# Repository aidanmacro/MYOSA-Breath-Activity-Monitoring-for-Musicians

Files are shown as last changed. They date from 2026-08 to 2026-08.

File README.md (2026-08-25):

## BreathSense - MYOSA Musical Breath Activity

<p align="center">
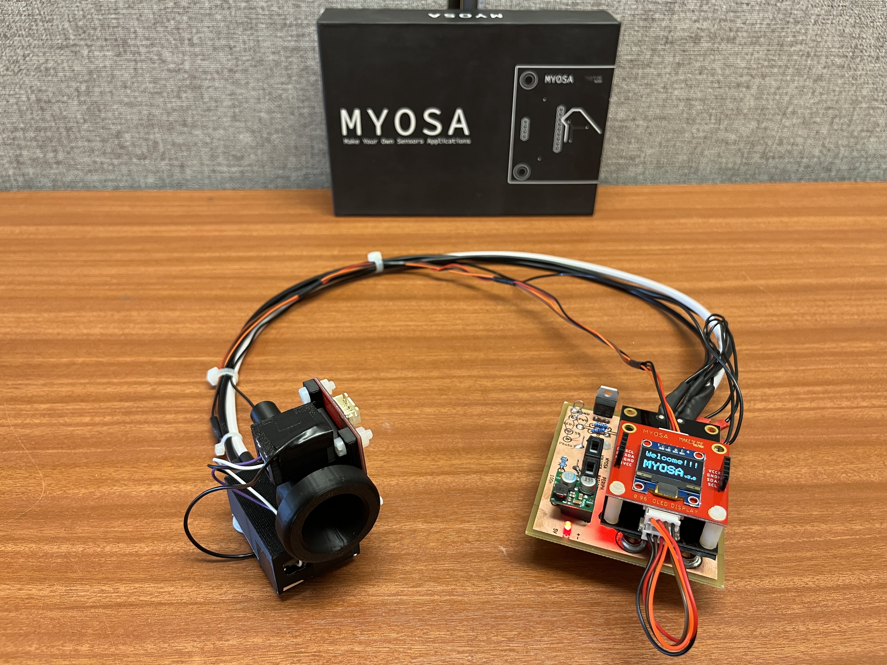
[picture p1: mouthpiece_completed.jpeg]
  <br/>
  <i>Breathsense: a CO2 Detecting mouthpiece using MYOSA board and sensors.</i>
</p>

## Acknowledgements

- Dr. Vincenzo Pusino
- Ben Allen
- University of Glasgow
- University of Glasgow Technical Staff

## Overview

Musicians rely heavily on breath control to shape dynamics, phrasing, tone and endurance, yet there are few accessible ways to measure breathing behaviour objectively during real performance. This project develops a real-time breath monitoring system designed specifically for musicians, using exhaled CO₂, pressure and temperature data to provide direct insight into how breath is being used while playing. The system is built around the MYOSA development board, providing an IoT-capable platform for sensor integration, wireless communication and real-time data logging. A custom Non-Dispersive Infrared (NDIR) CO₂ sensing system detects exhaled breath, while pressure and temperature measurements provide complementary information about breath activity and environmental variation. By combining these sensing methods with wireless data transmission and live visualisation, the project aims to provide musicians, teachers and researchers with a practical tool for analysing breath strength, timing and consistency during practice and performance.

#### Key Features

  - Custom NDIR CO₂ Sensor to allow most direct measurement. 
  - Pressure sensor for additional cross validation data and enhanced insights. 
  - Built on the MYOSA MCU platform, small enough to clip to a belt or pocket, streaming data live
  - On device OLED display for seeing quick analytics 
  - Python based WiFi/IoT system enabling cloud computing for in depth real time signal processing.

## Demo / Examples

### Images

<p align="center">
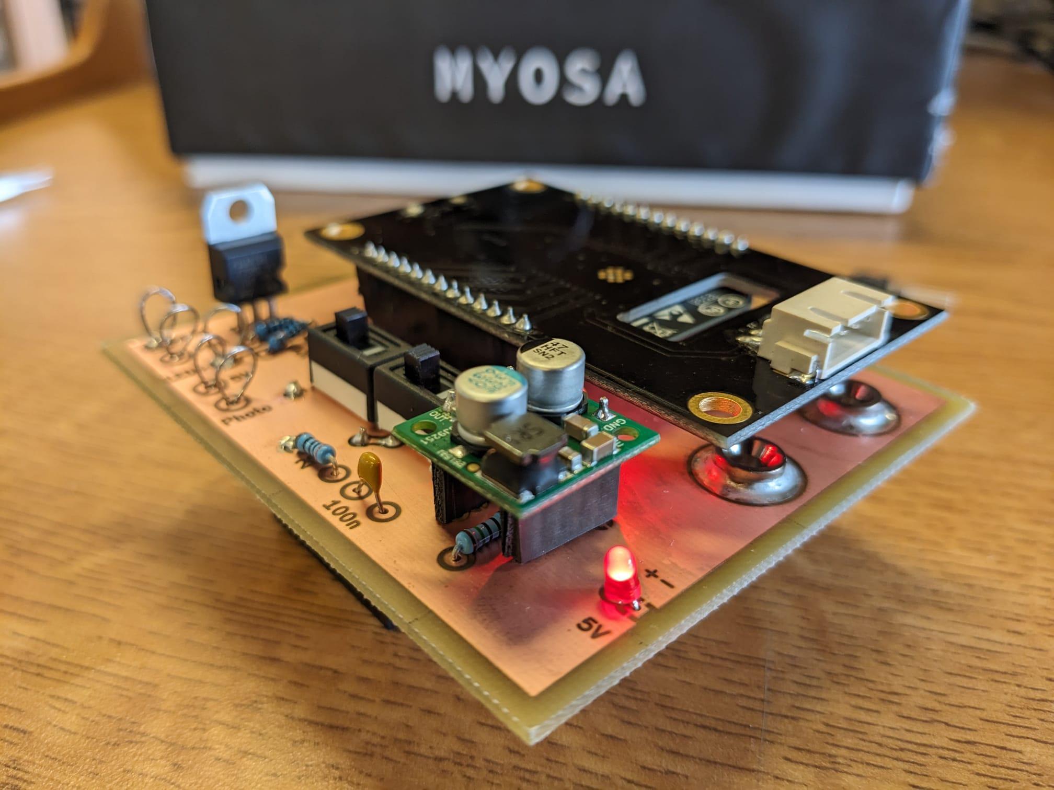
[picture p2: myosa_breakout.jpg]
  <br/>
  <i>Closeup of MYOSA breakout board.</i>
</p>

<p align="center">
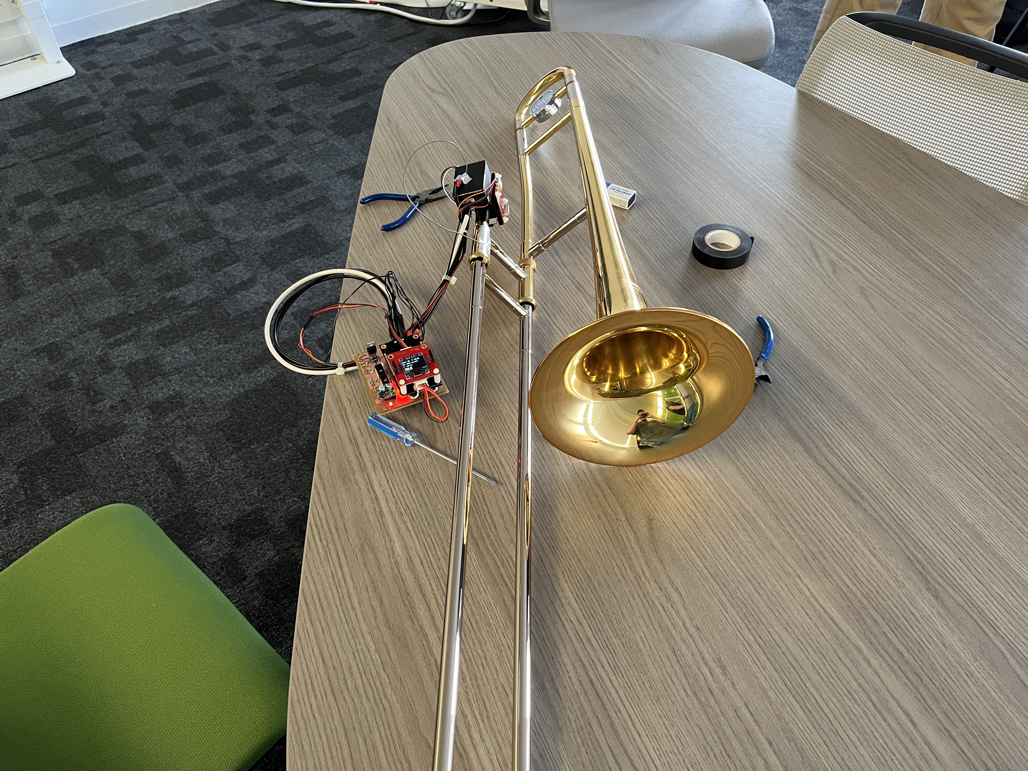
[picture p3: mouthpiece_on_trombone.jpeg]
  <br/>
  <i>Mouthpiece attached to real instrument.</i>
</p>

### Videos

<video controls width="100%">
  <source src="./breathsense_promovid.mp4" type="video/mp4">
</video>

## Features (Detailed)

## 1. NDIR CO₂ Sensing

The primary breath measurement is provided by a custom Non-Dispersive Infrared (NDIR) sensing system. CO₂ absorbs infrared radiation at specific wavelengths, so the concentration of CO₂ in exhaled breath can be inferred from the reduction in transmitted infrared light.

A mid-wave infrared (MWIR) LED is used as the optical source. The LED is pulsed rather than operated continuously, reducing average power consumption while also allowing the system to distinguish the desired optical signal from ambient infrared radiation and other sources of interference.

The emitted infrared light passes through the mouthpiece and the musician's exhaled breath before reaching a photodiode. As the concentration of CO₂ in the airflow changes, the amount of infrared radiation reaching the photodiode changes accordingly. The photodiode output is converted into a measurable voltage using an analogue front end before being sampled by the MYOSA board.

The system uses synchronous detection to improve the measurement. The photodiode is sampled in synchronisation with the LED pulses, allowing the signal measured when the LED is active to be compared with the background signal when it is inactive. This helps reject ambient infrared light and other sources of background variation.

The resulting CO₂ signal is used as a proxy for breath activity. Rather than attempting to measure the musician's breathing volume directly, the system provides a real-time indication of changes in exhaled CO₂ as the musician plays.

## 2. Pressure and Temperature Sensing

The optical CO₂ measurement is complemented by pressure and temperature measurements from a BMP180 sensor connected to the MYOSA board over I²C.

Pressure provides an independent measurement of activity within the mouthpiece. Changes in mouthpiece pressure can therefore be compared with the CO₂ signal to help distinguish genuine breath activity from changes or noise in the optical measurement.

Temperature is also recorded because the operating environment of the sensor can change during use. Monitoring temperature provides additional information for accounting for environmental variation and thermal drift in the measurements.

Combining the three measurements gives a more informative representation of breath activity than relying on the CO₂ channel alone.

## 3. Real-Time Breath Monitoring

The sensor data is processed into a real-time representation of the musician's breath activity. Changes in the measured CO₂ concentration can be visualised as a capnogram, allowing the user to observe the timing and relative strength of their breath while playing.

The pressure signal provides an additional reference alongside the CO₂ measurement, while temperature data can be used to identify environmental changes and compensate for drift.

This allows breath activity to be observed during actual playing rather than requiring the musician to perform a separate breathing test.

## 4. MYOSA Integration and Wireless Data

The sensing hardware is integrated with the MYOSA development board, which acts as the central controller for the system. The board controls the pulsed LED, reads the analogue CO₂ sensing circuitry, and communicates with the BMP180 over I²C.

The measurements are combined into a timestamped data stream and transmitted wirelessly to an external computer. This separates the sensing hardware from the visualisation system, allowing the musician to carry the relatively small sensing unit while viewing the measurements on a separate device.

Wireless transmission also allows measurements to be logged for later analysis rather than limiting the system to live monitoring.

## 5. Real-Time Visualisation

A Python and PyQt desktop application receives the wireless sensor data and displays the CO₂, pressure and temperature channels in real time.

The application performs additional signal processing and filtering before displaying the measurements, allowing the user to see changes in breath activity as they occur.

Session data can also be buffered for later review, making it possible to compare different playing sessions and examine breath behaviour beyond the immediate live display.

## 6. Potential Musical Application

By capturing quantifiable breath data during real playing, this system opens up several practical applications:

- **Practice feedback** musicians can see how their breath support and timing align with phrasing, dynamics, and endurance across a piece, rather than relying on subjective feel alone.
- **Teaching aid** instructors can use recorded breath data to give concrete, visual feedback on breath control technique, rather than description alone.
- **Endurance and consistency tracking** repeated sessions can be compared over time to track improvements in breath efficiency or stamina for demanding passages.
- **Research** objective breath-activity data across players/instruments could support studies into breath technique and fatigue in wind and brass performance.

## Usage Instructions

The final version of the device is envisioned to work like so:

- Attach mouthpiece to wind instrument and place MYOSA in pocket/hook to belt
- Run accompanying app on phone/computing device
- Allow hardware a few seconds unplayed to calibrate CO2 background level
- Practise instrument as normal, playing along to sheet music on app
- Compare breath activity in app in realtime and/or observe collected data at end of piece

## Tech Stack

### Hardware

| Component | Part | Role |
|---|---|---|
| MCU / wireless | MYOSA development board | Master controller — drives sensing, fuses data, streams wirelessly to host computer/Cloud |
| CO₂ emitter | L15895-0430MA LED | Pulsed mid-wavelength infrared (MWIR) source, tuned to a CO₂ absorption band |
| CO₂ detector | P16112-011MA photodiode | Measures transmitted IR intensity after passing through the breath sample |
| Pressure / temperature | BMP180 (Minkit breakout) | I²C sensor providing an independent breath-pressure signal and temperature compensation |
| Onboard display | 0.96" OLED Display (Minkit breakout) | I²C enabled, providing on device quick insights for potential offline use|
| Mechanical | 3D-printed trombone mouthpiece | Directs exhaled breath through the sensing chamber; mounts sensor package in the airflow path (Based on Popular Bach 12C Design) |
| PCB | Custom board (see `KiCAD/`) | Houses the analog front end and sensor interconnects |

#### Analog Front End

The CO₂ channel is the most sensitive part of the hardware, since NDIR absorption signals are small relative to the raw photodiode output. The front end is built around a **pulsed detection scheme**:

1. **LED pulsing** — the MWIR LED is driven in short pulses (rather than continuously) by the MYOSA board. Pulsing reduces average power draw and, more importantly, lets the readout distinguish the LED's signal from ambient IR and photodiode drift.
2. **Photodiode readout** — the photodiode's current output is converted to a voltage via a transimpedance amplifier (TIA), since photodiode signals are typically too small and too high-impedance to read directly with an ADC.
3. **Filtering** — the amplified signal is filtered to reject noise outside the LED's pulse frequency and suppress ambient light interference.
4. **Synchronous sampling** — the MYOSA board samples the photodiode signal in sync with the LED pulse (on-pulse vs off-pulse), allowing the background/ambient signal to be subtracted from the CO₂-modulated signal. This differential approach is what makes the CO₂ absorption measurable despite a noisy optical environment.
5. **Digitisation** — the conditioned analog signal is read via the MYOSA board's ADC and combined in firmware with the BMP180's I²C readings.

### Software

**Firmware — Arduino C++ (runs on MYOSA)**
- Drives LED pulse timing and synchronises photodiode ADC sampling with each pulse
- Polls the BMP180 over I²C for pressure and temperature
- Fuses CO₂, pressure, and temperature readings into a single timestamped data frame
- Streams the fused data frame wirelessly to the host computer

**Desktop application — Python + PyQt**
- Listens for the incoming data stream from the MYOSA board and parses each frame into CO₂, pressure, and temperature values
- Does enhanced signal processing and filtering
- Plots all three channels live using PyQt's graphing widgets, updating in real time as the musician plays
- Buffers session data for post-session review, and (per the Usage Instructions) supports comparing breath activity against sheet music playback

## Requirements / Installation

**Dependencies** are listed in `requirements.txt` — install with:
```bash
pip install -r requirements.txt
```
**User Interface** run the current user interface using:
```bash
python3 .\Code\app_code\Breathsense_GUI.py
```

## Repository Structure

| Folder | Contents |
|---|---|
| [`Code/`](Code) | Arduino C++ firmware for the MYOSA board (sensor reading, LED pulsing, I²C fusion, wireless streaming) and the Python/PyQt desktop visualisation app |
| [`KiCAD/`](KiCAD) | PCB schematics and layout for the custom analog front end (NDIR CO₂ sensing circuitry) |
| [`Mechanical/`](Mechanical) | 3D-printable mouthpiece adapter design (based on a Bach 12C mouthpiece) that houses the sensor package in the airflow path |

## License MIT License

Copyright (c) 2026 aidanmacro

Permission is hereby granted, free of charge, to any person obtaining a copy of this software and associated documentation files (the "Software"), to deal in the Software without restriction, including without limitation the rights to use, copy, modify, merge, publish, distribute, sublicense, and/or sell copies of the Software, and to permit persons to whom the Software is furnished to do so, subject to the following conditions:

The above copyright notice and this permission notice shall be included in all
copies or substantial portions of the Software.

THE SOFTWARE IS PROVIDED "AS IS", WITHOUT WARRANTY OF ANY KIND, EXPRESS OR IMPLIED, INCLUDING BUT NOT LIMITED TO THE WARRANTIES OF MERCHANTABILITY, FITNESS FOR A PARTICULAR PURPOSE AND NONINFRINGEMENT. IN NO EVENT SHALL THE AUTHORS OR COPYRIGHT HOLDERS BE LIABLE FOR ANY CLAIM, DAMAGES OR OTHER LIABILITY, WHETHER IN AN ACTION OF CONTRACT, TORT OR OTHERWISE, ARISING FROM, OUT OF OR IN CONNECTION WITH THE SOFTWARE OR THE USE OR OTHER DEALINGS IN THE
SOFTWARE.

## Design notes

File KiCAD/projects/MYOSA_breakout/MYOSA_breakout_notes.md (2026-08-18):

**NOTES**

&#x09;**PinHeader\_1x13\_P2.54mm\_Vertical.step**

&#x09;

&#x09;Uni has KiCAD v9.01.

&#x09;

&#x09;CANT USE ADC2 WITH WIFI! Using 'sensor\_vp' as this is definitely ADC1\_CH0.	It doesn't have internal pulldown though so that's been added.	

&#x09;Pretty sure the onboard regulator will safely power the esp32 from VIN with	4.5-12V.

&#x09;Need high current for LED and 3V3 available for opamp circuit.

&#x09;Just use onboard 3V3 and external 5V? How about 4xAA at 6V?

&#x09;could 3v3 output on MYOSA power opamps? Yes, it doesn't really draw power.

&#x09;Want to make easy access for powering with PSU. Switch to choose between 	battery and PSU? If MYOSA is plugged in, still need 5V for LED.

&#x09;	battery: powering both MYOSA and LED

&#x09;	PSU: powering both MYOSA and LED

&#x09;	USB: Powers only MYOSA, battery/PSU required for LED

&#x09;Test points? 

&#x09;	

&#x09;	Voltage sources

&#x09;	PWM out

&#x09;	Either end of LED

**Measurements required/things to check**

&#x09;9V Battery holder

&#x09;LED Size

&#x09;Banana plugs

&#x09;Switches

&#x09;Connectors to BMP module/LED+Photodiode

&#x09;Should BMP180 be separate connector?

&#x09;Should battery be on other side?

**LED:** 1% duty cycle, 20us on, 1980us off (500Hz)

&#x09;3R4 series resistor drops 1.7V so LED has 3.3V across it, corresponding to 	\~450mA.

&#x09;P\_LED = 0.45 \* 3.3 \* 0.01 = 14.85mW

&#x09;P\_R\_SERIES = 0.45 \* 1.7 \* 0.01 = 7.65mW

**MOSFET**

&#x09;Switching freq = 500Hz

&#x09;Static drain-source on-resistance \~ 0.025R

&#x09;negligible power I think...

**MYOSA**

&#x09;Powered by 5V USB or 3.3Vin.

&#x09;Probably want to maintain 5V supply to LED so that there is a current 	limiting resistor and some headroom? Otherwise, could power with 3.3V and 	no resistor. Still need something that can supply the current spikes, MYOSA 	can't.

&#x09;ESP32 Max transmission power: 239mA (average) \* 3.3 = 789mW (Peak 379mA)

&#x09;lowest = 165mA \* 3.3 = 545mW.

has **AMS1117 (T33 F80LC)** fixed 3V3 voltage regulator.

&#x09;< 1A output

&#x09;< Absolute max 15V input (4.5-7V recommended)

&#x09;1.3V dropout at worst so 4.6V minimum

**ESP32-WROOM-32E**

&#x09;Absolute max input 3.6V. Provided 3V3 by AMS1117.

&#x09;All GPIO pins support either LED or motor PWM.

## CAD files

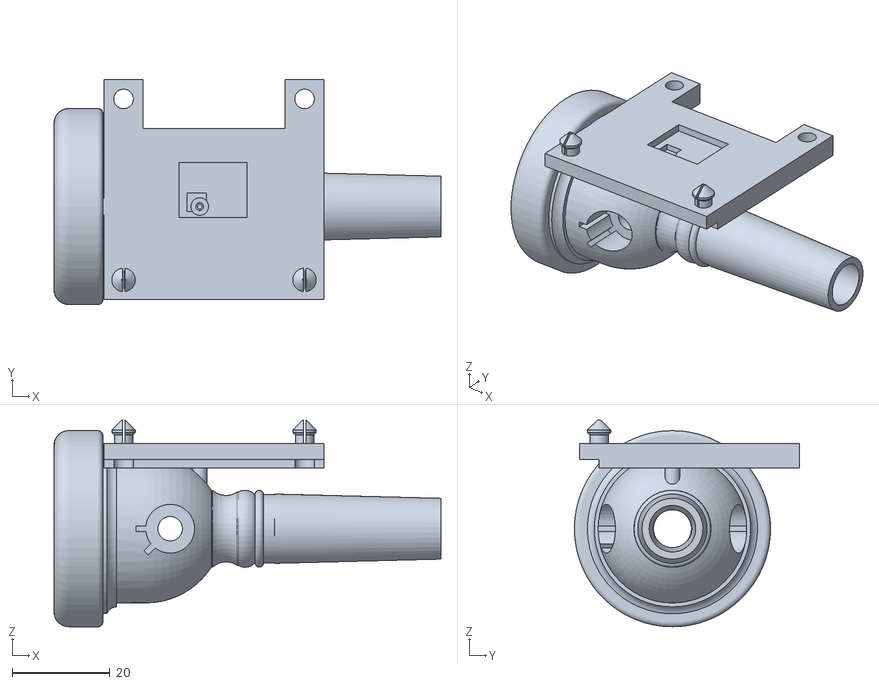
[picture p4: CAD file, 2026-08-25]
Mechanical/Mouthpiece/STLs/Full_Assem - Mouthpiece_SLD-1.STL
79.1 x 46.1 x 42.2

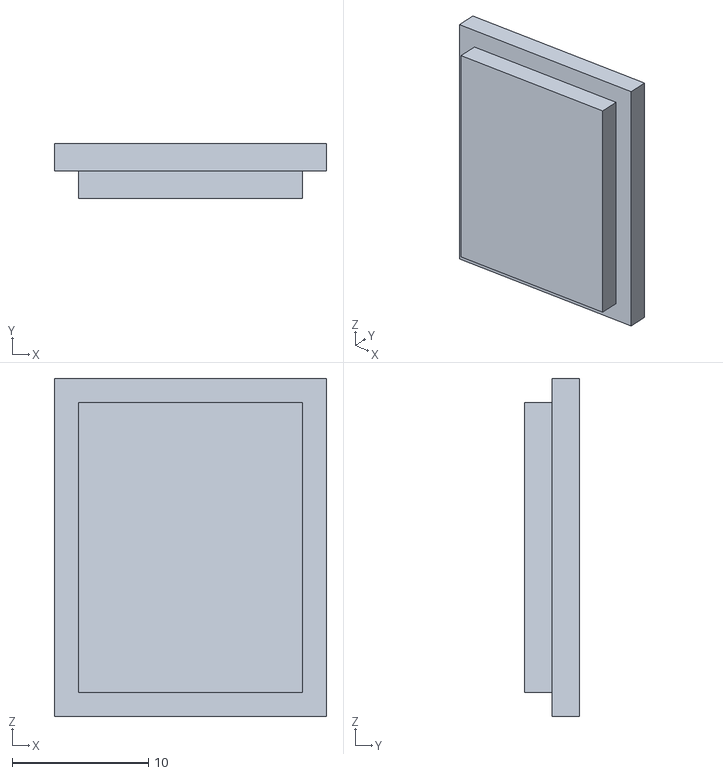
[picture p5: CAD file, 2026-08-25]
Mechanical/Mouthpiece/STLs/Full_Assem - LED_Holder_Lid-1.STL
20.0 x 4.00 x 24.8

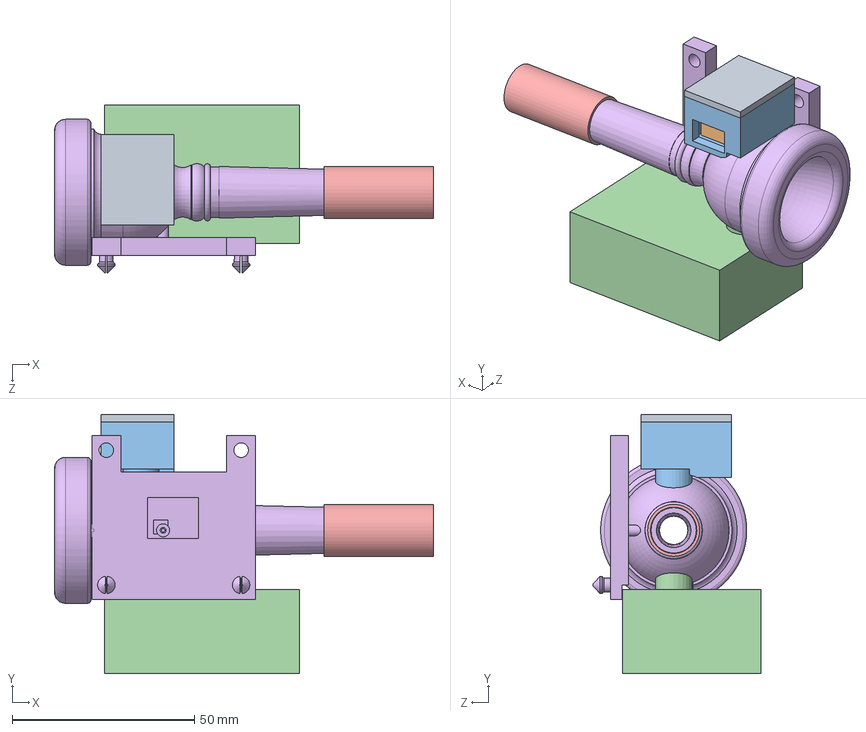
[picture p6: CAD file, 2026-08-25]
Mechanical/Mouthpiece/Full_Assem.SLDASM
104.0 x 71.1 x 46.2 mm
Mouthpiece_SLD
TrombonePort
Photodiode_Holder
LED_Holder
LED_PCB
LED_Holder_Lid

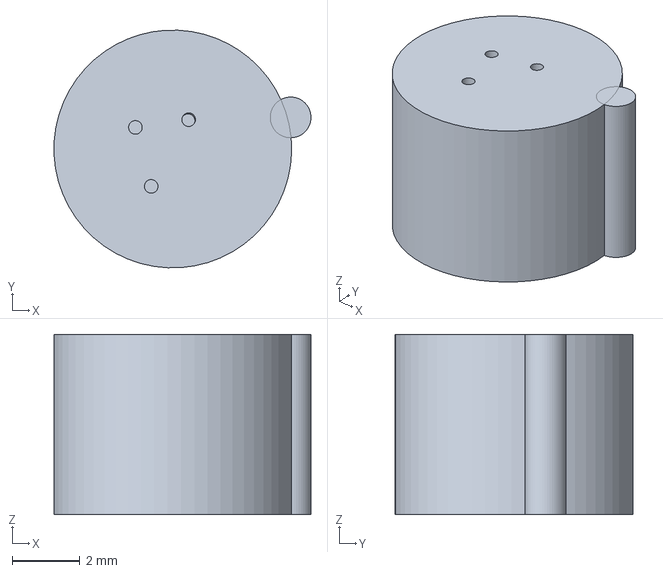
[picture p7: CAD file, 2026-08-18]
KiCAD/DST5_custom_library/3dmodels/TO46 Sheath.step
7.57 x 6.99 x 5.30 mm

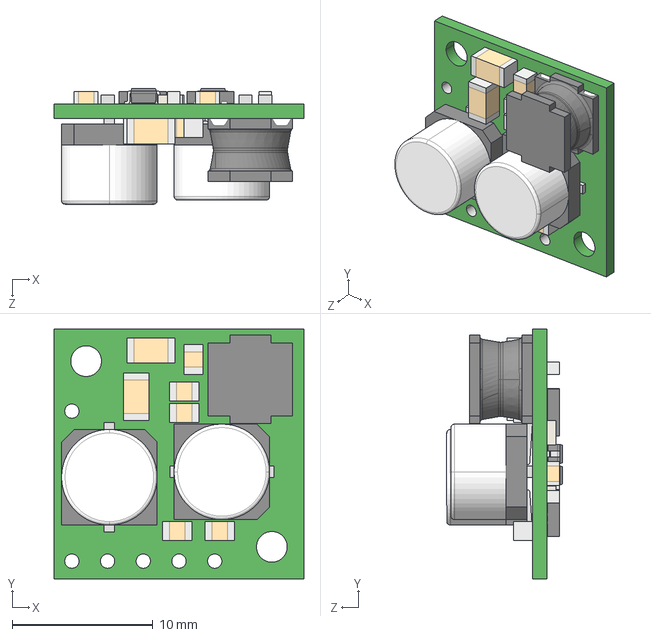
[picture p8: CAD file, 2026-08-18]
KiCAD/external_libs/pololu/d24v22fx-step-down-voltage-regulator.step
17.8 x 17.8 x 8.22 mm

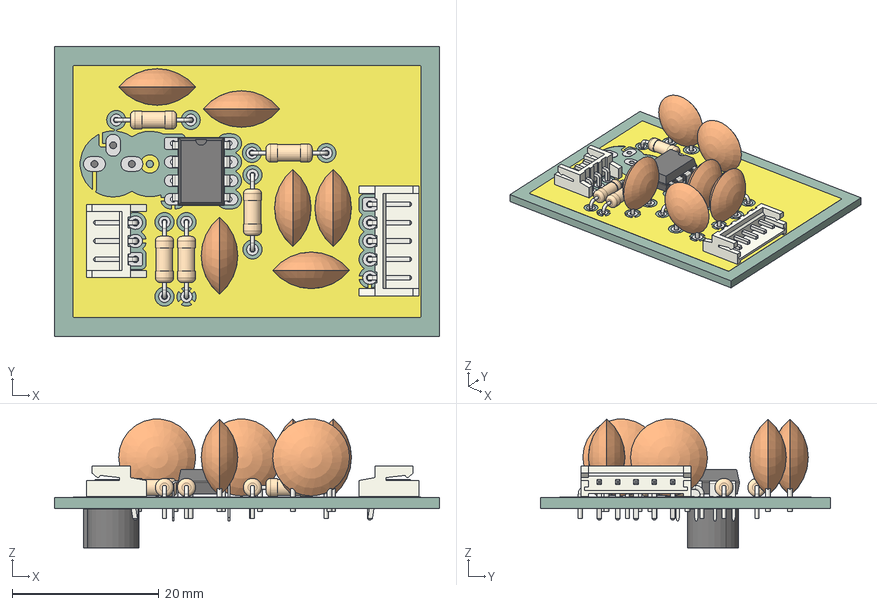
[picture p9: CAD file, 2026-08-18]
KiCAD/projects/photodiode TIA circuit/photodiode_tia_circuit/.step
52.5 x 39.5 x 17.5 mm
DIP-8_W7.62mm
JST_EH_S5B-EH_1x05_P2.50mm_Horizontal
C_Disc_D10.5mm_W5.0mm_P5.00mm x 6
R_Axial_DIN0207_L6.3mm_D2.5mm_P10.16mm_Horizontal x 5
JST_EH_S3B-EH_1x03_P2.50mm_Horizontal
TO46 Sheath
photodiode_tia_circuit_copper
photodiode_tia_circuit_pad
photodiode_tia_circuit_via
photodiode_tia_circuit_PCB

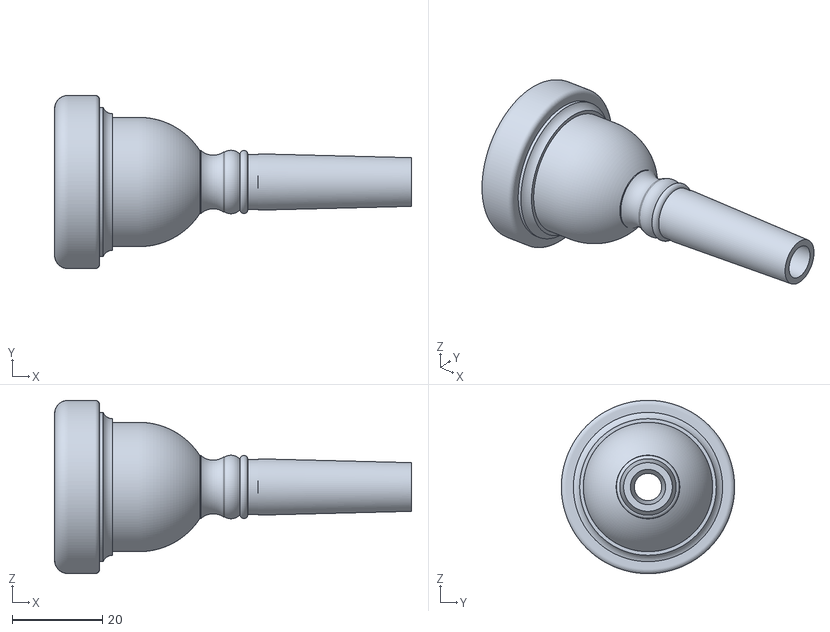
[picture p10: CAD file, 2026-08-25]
Mechanical/Mouthpiece/12C_Mouthpiece.stl
79.1 x 38.4 x 38.4

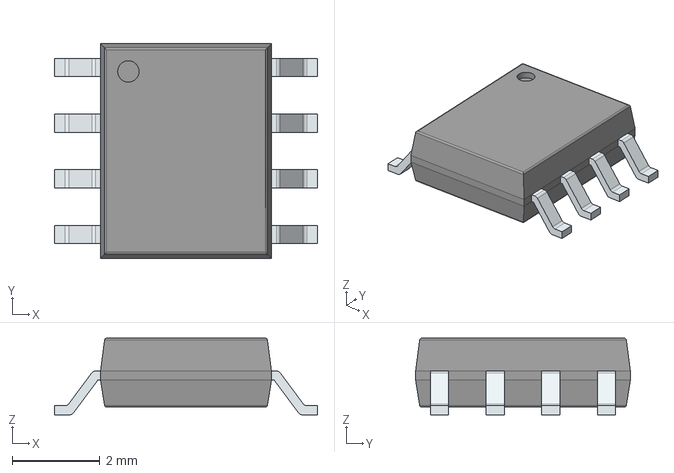
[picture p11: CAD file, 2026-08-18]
KiCAD/DST5_custom_library/3dmodels/STCS05DR.stp
6.00 x 4.90 x 1.75 mm
PinsArrayLR

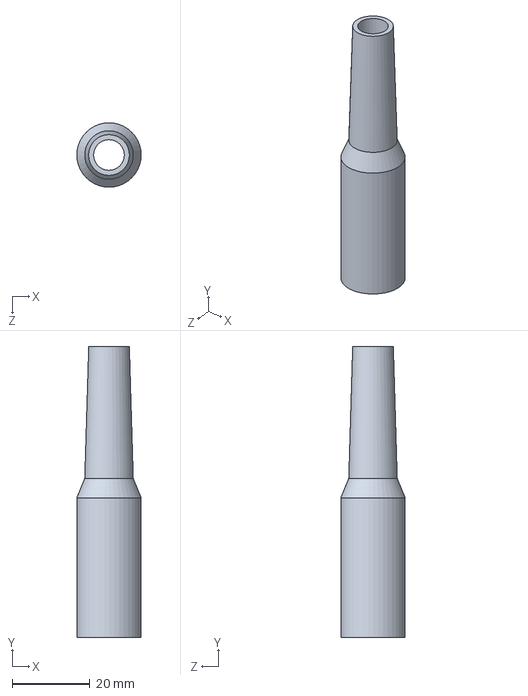
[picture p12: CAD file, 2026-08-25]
Mechanical/Mouthpiece/Adapter.SLDPRT
16.6 x 75.0 x 16.6 mm

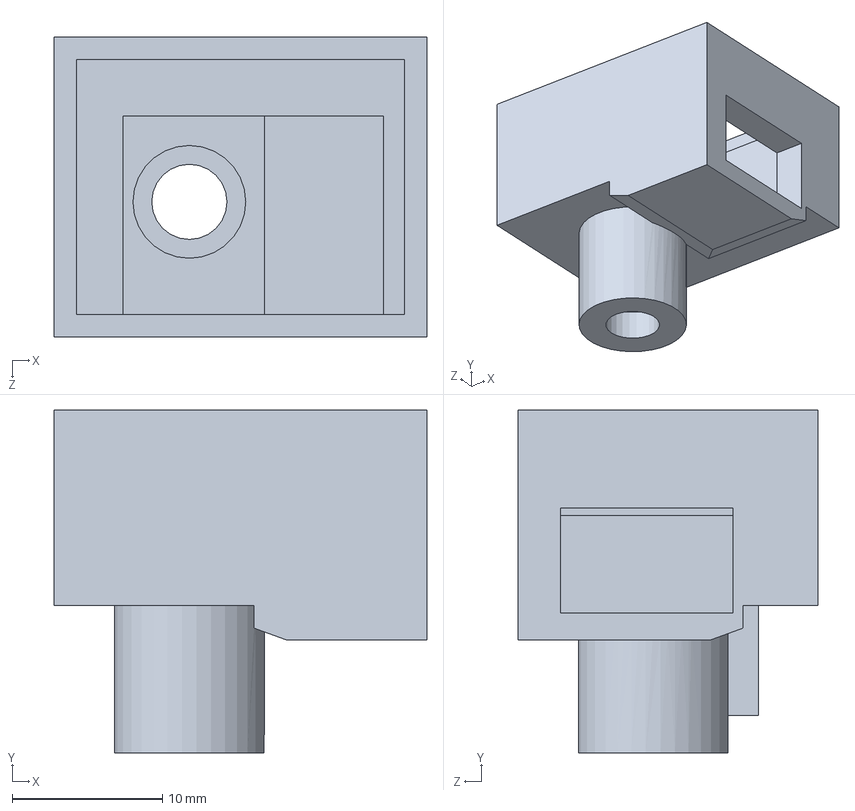
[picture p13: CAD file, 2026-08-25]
Mechanical/Mouthpiece/LED_Holder.SLDPRT
24.8 x 22.8 x 20.0 mm

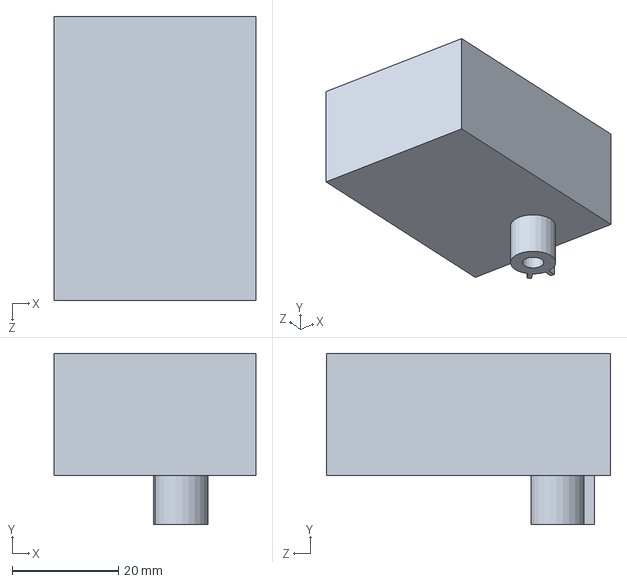
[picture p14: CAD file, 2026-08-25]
Mechanical/Mouthpiece/Photodiode_Holder.SLDPRT
38.0 x 32.3 x 53.5 mm

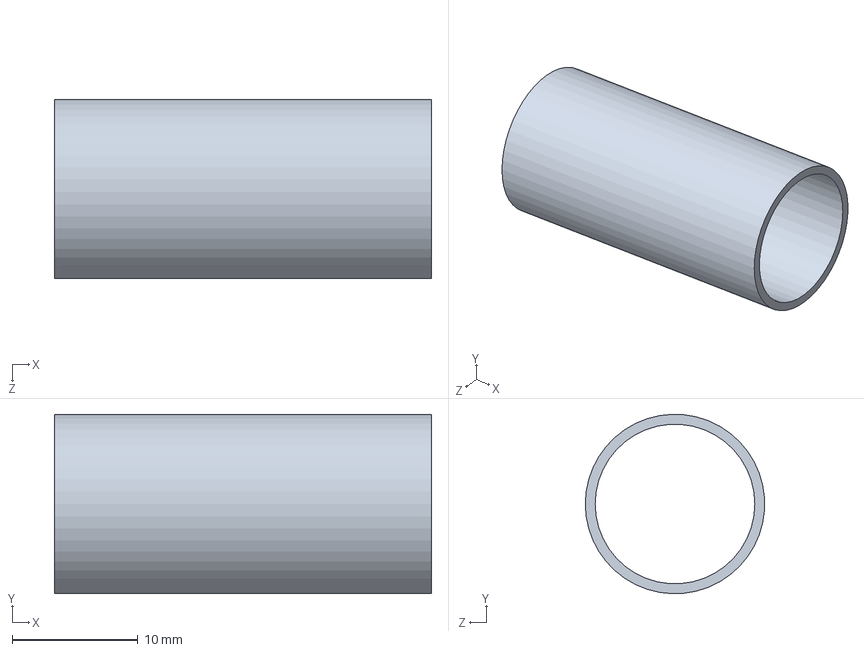
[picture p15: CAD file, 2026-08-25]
Mechanical/Mouthpiece/TrombonePort.SLDPRT
30.0 x 14.3 x 14.3 mm

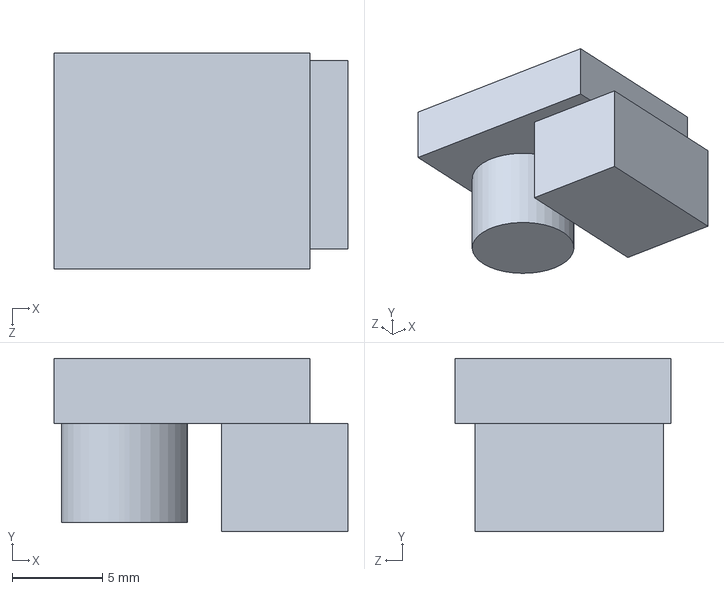
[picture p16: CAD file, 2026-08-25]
Mechanical/Mouthpiece/LED_PCB.SLDPRT
16.3 x 9.60 x 11.9 mm

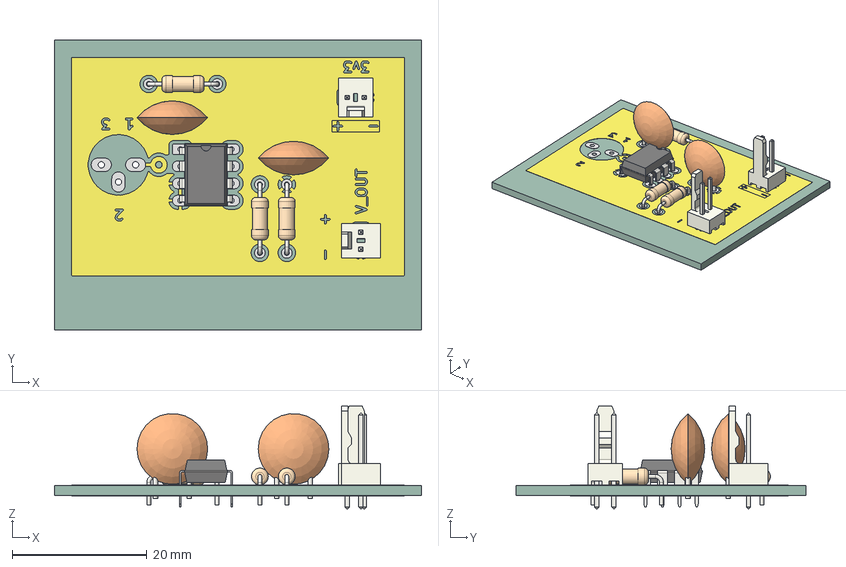
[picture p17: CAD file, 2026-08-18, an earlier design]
KiCAD/projects/photodiode TIA circuit/photodiode_tia_circuit/old_version.step
54.5 x 43.0 x 15.3 mm
DIP-8_W7.62mm
C_Disc_D10.5mm_W5.0mm_P5.00mm x 2
R_Axial_DIN0207_L6.3mm_D2.5mm_P10.16mm_Horizontal x 3
Molex_KK-254_AE-6410-02A_1x02_P2.54mm_Vertical x 2
photodiode_tia_circuit_copper
photodiode_tia_circuit_pad
photodiode_tia_circuit_via
photodiode_tia_circuit_PCB

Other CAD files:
Mechanical/Mouthpiece/LED_Holder_Lid.SLDPRT
Mechanical/Mouthpiece/Mouthpiece_SLD.SLDPRT
Mechanical/Mouthpiece/STLs/Adapter.STL
Mechanical/Mouthpiece/STLs/Full_Assem - LED_Holder-1.STL

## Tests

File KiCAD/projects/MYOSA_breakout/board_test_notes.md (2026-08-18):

**TO TEST**

PWM output

MOSFET switching

MWIR LED pulsing

**TESTED**

**PSU power:** 5V output from regulator confirmed, LED lights

**Battery power:** 4.977V from regulator, LED lights

**MYOSA pins:** 

5V confirmed at Vin pin

Powers on with 5Vin with both PSU and battery and successfully regulates to 3V3 output

**NOTES**

Seeing ~0.3V at LED cathode when the LED isn't connected? 

&nbsp;	

&nbsp;	it's just floating; it's still there when the power's off.

LED very bright; there's 2V across it. Could maybe increase resistor.

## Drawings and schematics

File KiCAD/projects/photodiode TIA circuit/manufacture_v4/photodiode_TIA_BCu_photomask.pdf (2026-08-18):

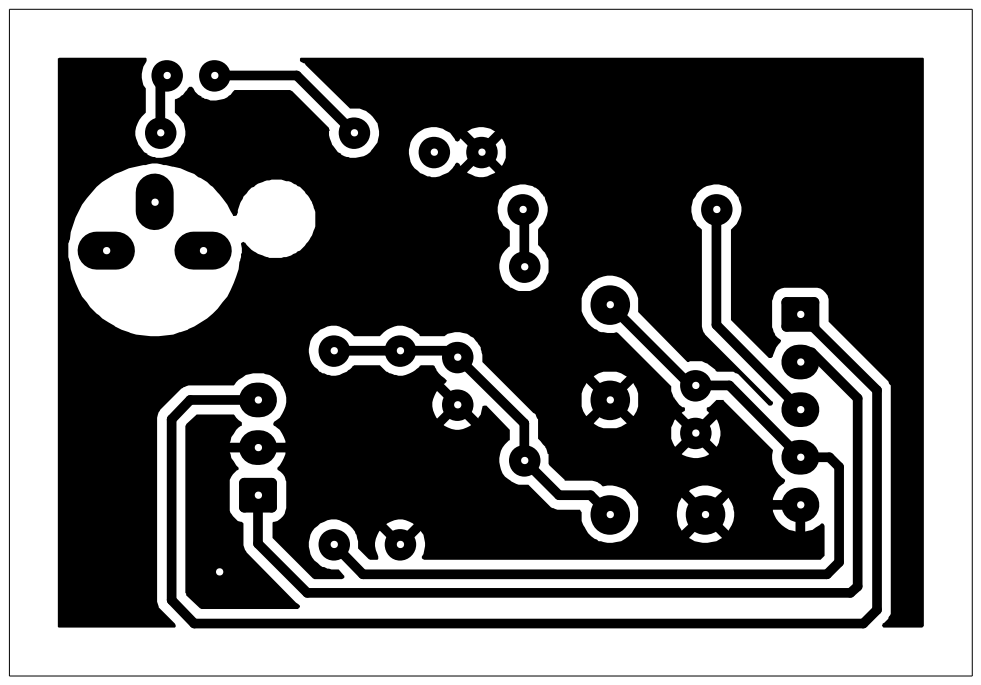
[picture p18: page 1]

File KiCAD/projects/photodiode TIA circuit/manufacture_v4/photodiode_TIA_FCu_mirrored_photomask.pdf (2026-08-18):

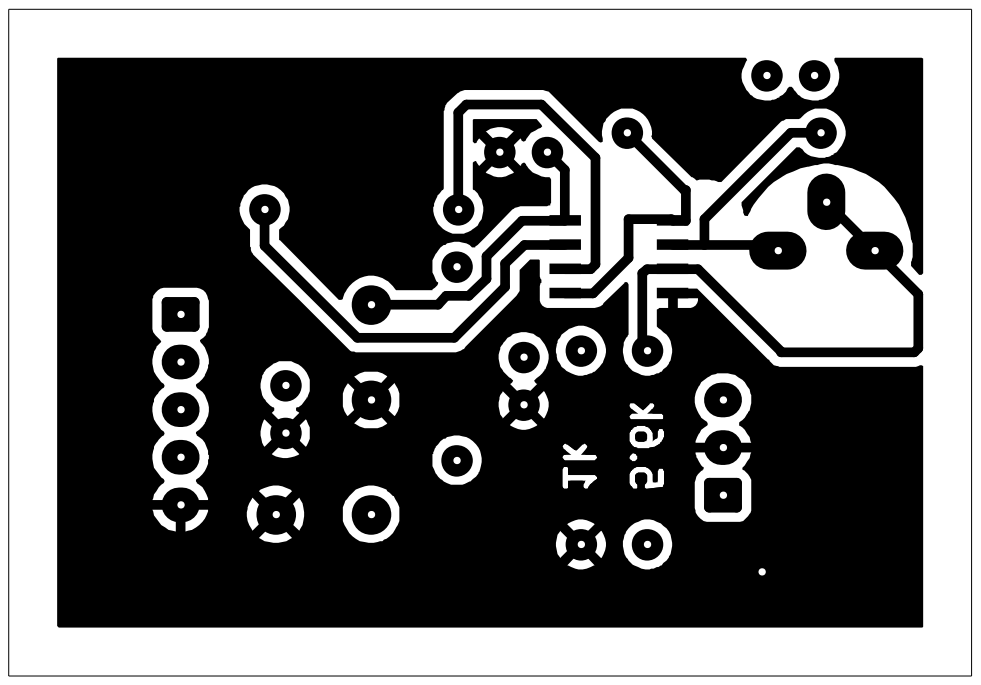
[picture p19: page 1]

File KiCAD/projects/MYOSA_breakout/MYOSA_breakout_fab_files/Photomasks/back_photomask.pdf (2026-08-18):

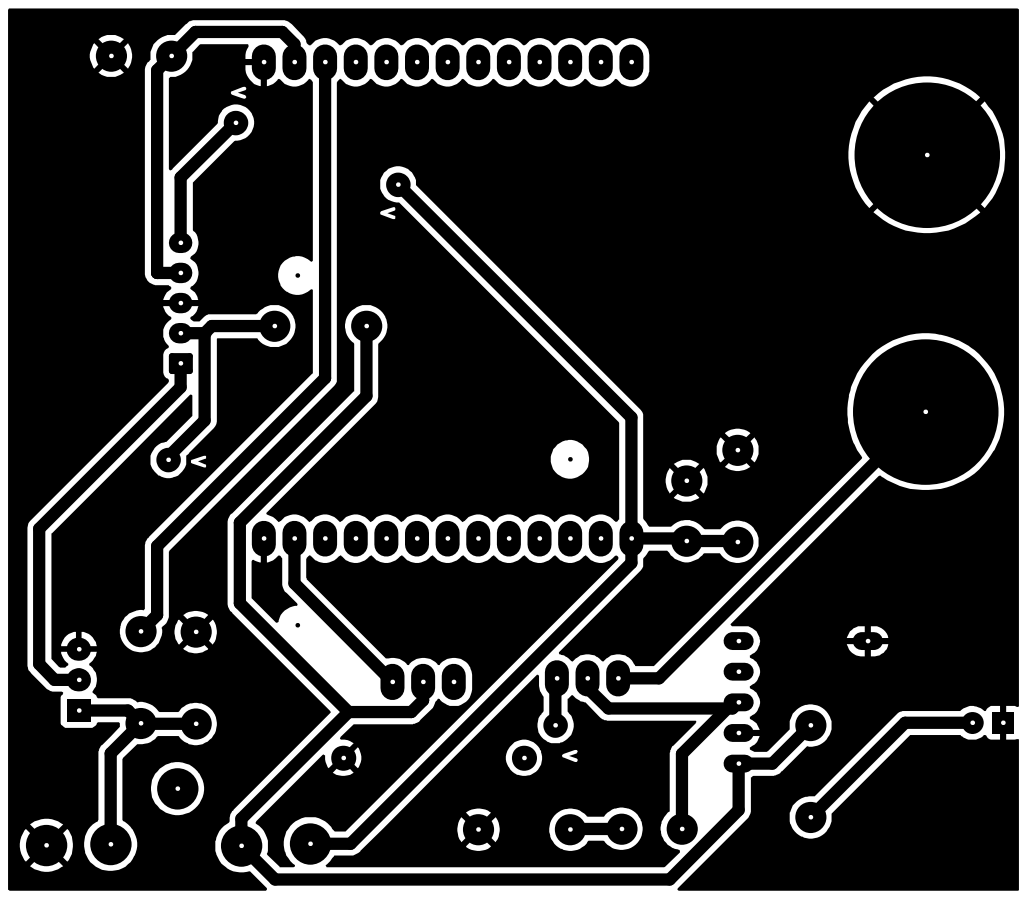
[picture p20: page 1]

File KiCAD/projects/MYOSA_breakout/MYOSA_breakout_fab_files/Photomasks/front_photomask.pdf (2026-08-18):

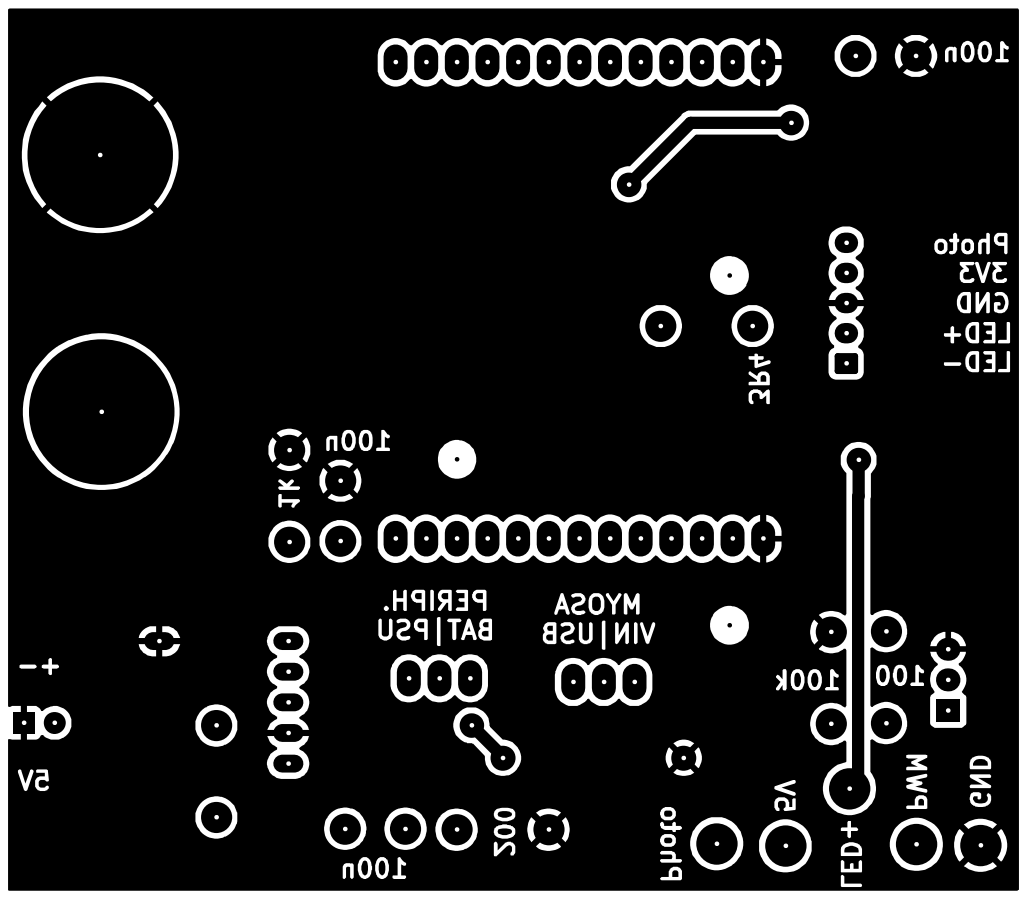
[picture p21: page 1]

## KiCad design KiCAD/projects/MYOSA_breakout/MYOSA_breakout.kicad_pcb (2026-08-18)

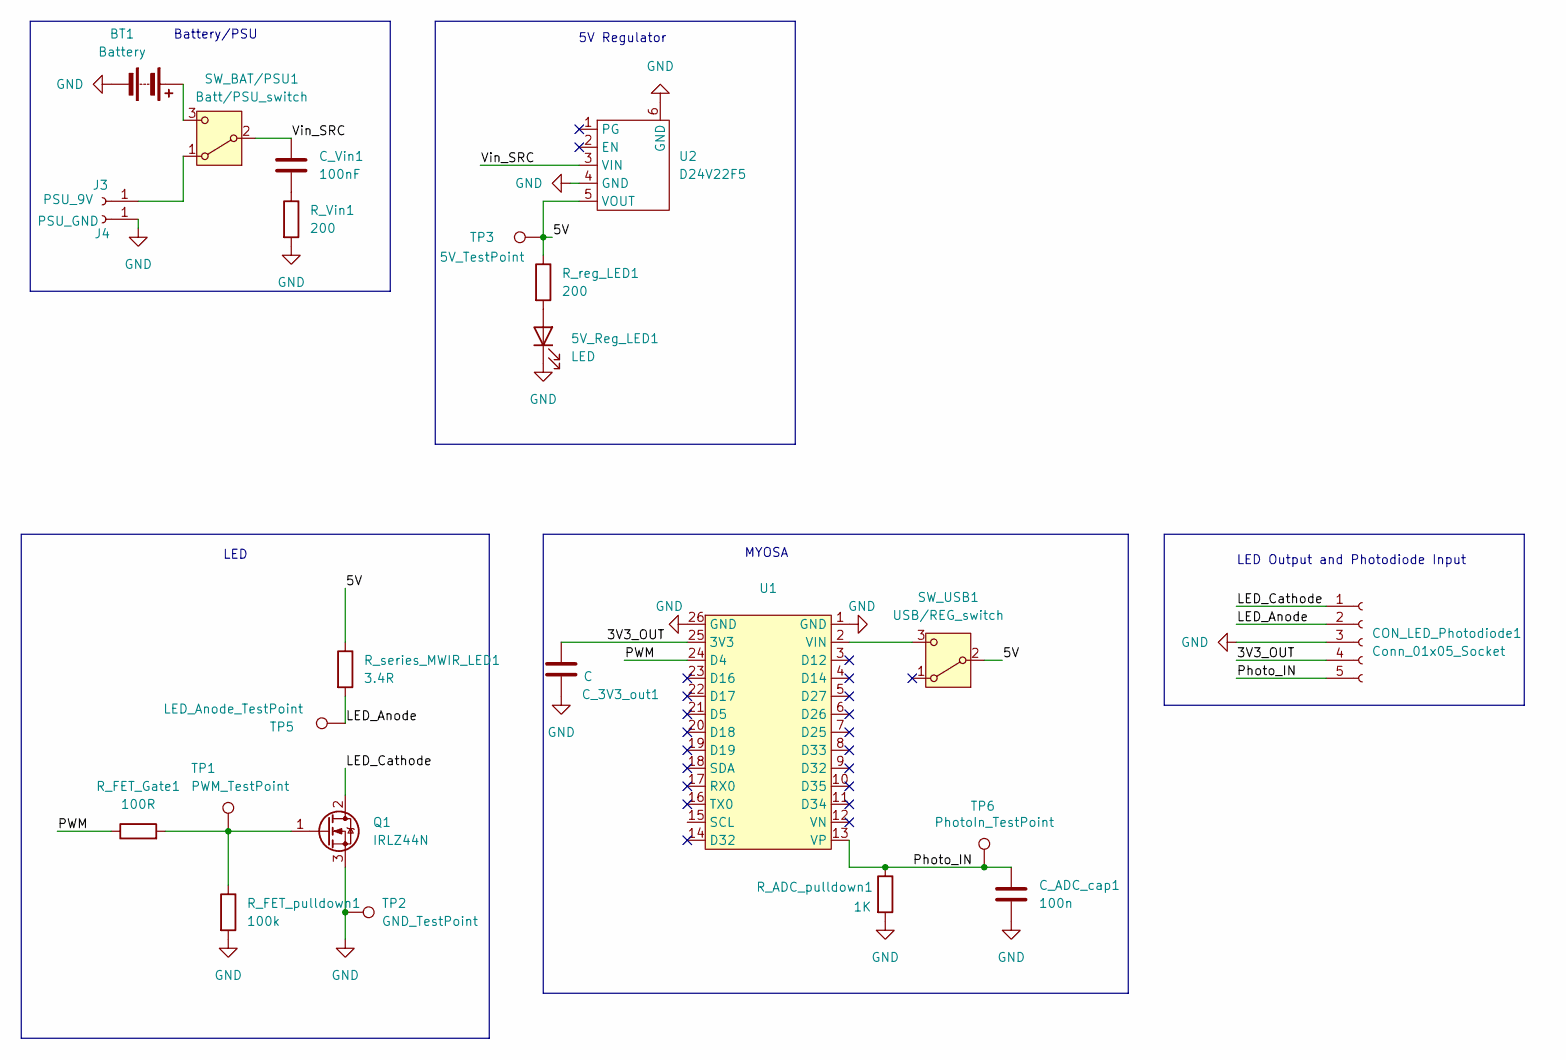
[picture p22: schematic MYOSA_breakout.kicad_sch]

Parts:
5V_Reg_LED1: LED; LED_D5.0mm
BT1: Battery; BatteryHolder_MPD_BA9VPC_1xPP3
CON_LED_Photodiode1: Conn_01x05_Socket; JST_EH_S5B-EH_1x05_P2.50mm_Horizontal
C_3V3_out1: C; C_Disc_D5.0mm_W2.5mm_P5.00mm
C_ADC_cap1: 100n; C_Disc_D5.0mm_W2.5mm_P5.00mm
C_Vin1: 100nF; C_Disc_D5.0mm_W2.5mm_P5.00mm
J3: PSU_9V; Banana_Jack_1Pin
J4: PSU_GND; Banana_Jack_1Pin
Q1: IRLZ44N; TO-220-3_Vertical
R_ADC_pulldown1: 1K; R_Axial_DIN0207_L6.3mm_D2.5mm_P7.62mm_Horizontal
R_FET_Gate1: 100R; R_Axial_DIN0207_L6.3mm_D2.5mm_P7.62mm_Horizontal
R_FET_pulldown1: 100k; R_Axial_DIN0207_L6.3mm_D2.5mm_P7.62mm_Horizontal
R_Vin1: 200; R_Axial_DIN0207_L6.3mm_D2.5mm_P7.62mm_Horizontal
R_reg_LED1: 200; R_Axial_DIN0207_L6.3mm_D2.5mm_P7.62mm_Horizontal
R_series_MWIR_LED1: 3.4R; R_Axial_DIN0207_L6.3mm_D2.5mm_P7.62mm_Horizontal
SW_BAT/PSU1: Batt/PSU_switch; SW_Slide-03_Wuerth-WS-SLTV_10x2.5x6.4_P2.54mm
SW_USB1: USB/REG_switch; SW_Slide-03_Wuerth-WS-SLTV_10x2.5x6.4_P2.54mm
TP1: PWM_TestPoint; TestPoint_Loop_D2.50mm_Drill1.85mm
TP2: GND_TestPoint; TestPoint_Loop_D2.50mm_Drill1.85mm
TP3: 5V_TestPoint; TestPoint_Loop_D2.50mm_Drill1.85mm
TP5: LED_Anode_TestPoint; TestPoint_Loop_D2.50mm_Drill1.85mm
TP6: PhotoIn_TestPoint; TestPoint_Loop_D2.50mm_Drill1.85mm
U1: MYOSA_ESP-32
U2: D24V22F5

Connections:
/3V3_OUT: CON_LED_Photodiode1.4, C_3V3_out1.1, U1.25 (3V3)
/5V: R_reg_LED1.1, R_series_MWIR_LED1.1, SW_USB1.2 (B), TP3.1, U2.5 (VOUT)
/LED_Anode: CON_LED_Photodiode1.2, R_series_MWIR_LED1.2, TP5.1
/LED_Cathode: CON_LED_Photodiode1.1, Q1.2 (D)
/PWM: R_FET_Gate1.1, U1.24 (D4)
/Photo_IN: CON_LED_Photodiode1.5, C_ADC_cap1.1, R_ADC_pulldown1.1, TP6.1, U1.13 (VP)
/Vin_SRC: C_Vin1.1, SW_BAT/PSU1.2 (B), U2.3 (VIN)
GND: 5V_Reg_LED1.1 (K), BT1.2 (-), CON_LED_Photodiode1.3, C_3V3_out1.2, C_ADC_cap1.2, J4.1, Q1.3 (S), R_ADC_pulldown1.2, R_FET_pulldown1.2, R_Vin1.2, TP2.1, U1.1 (GND), U1.26 (GND), U2.4 (GND), U2.6 (GND)
unnamed: 5V_Reg_LED1.2 (A), R_reg_LED1.2
unnamed: BT1.1 (+), SW_BAT/PSU1.3 (C)
unnamed: C_Vin1.2, R_Vin1.1
unnamed: J3.1, SW_BAT/PSU1.1 (A)
unnamed: Q1.1 (G), R_FET_Gate1.2, R_FET_pulldown1.1, TP1.1
unnamed: SW_USB1.3 (C), U1.2 (VIN)

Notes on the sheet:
LED
LED Output and Photodiode Input
MYOSA
Battery/PSU
5V Regulator

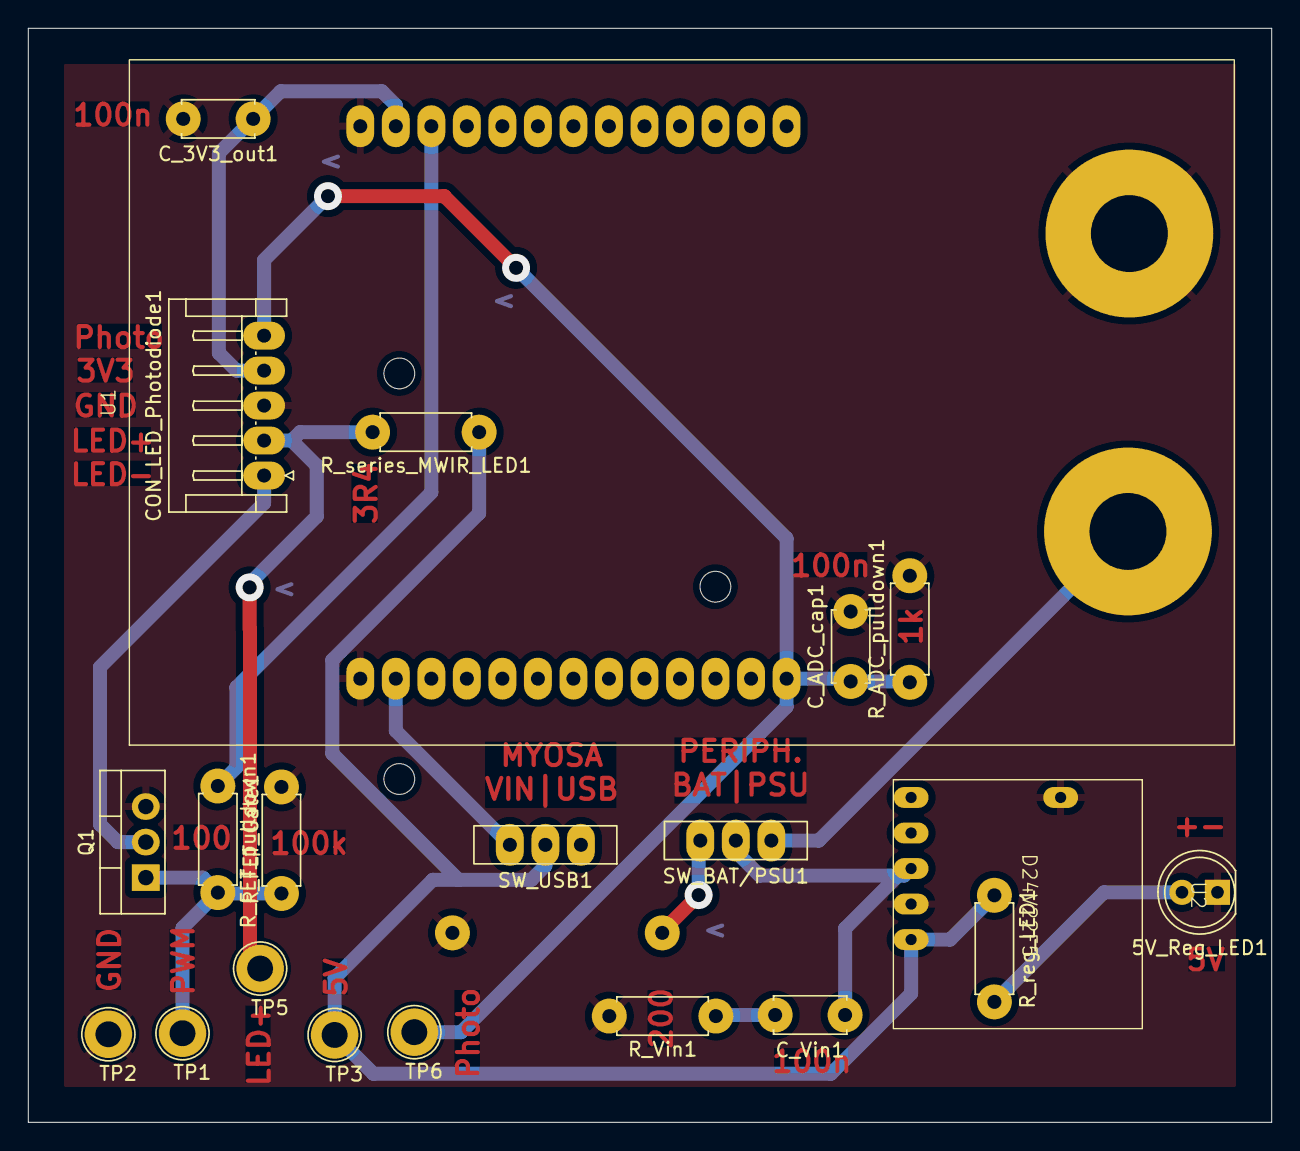
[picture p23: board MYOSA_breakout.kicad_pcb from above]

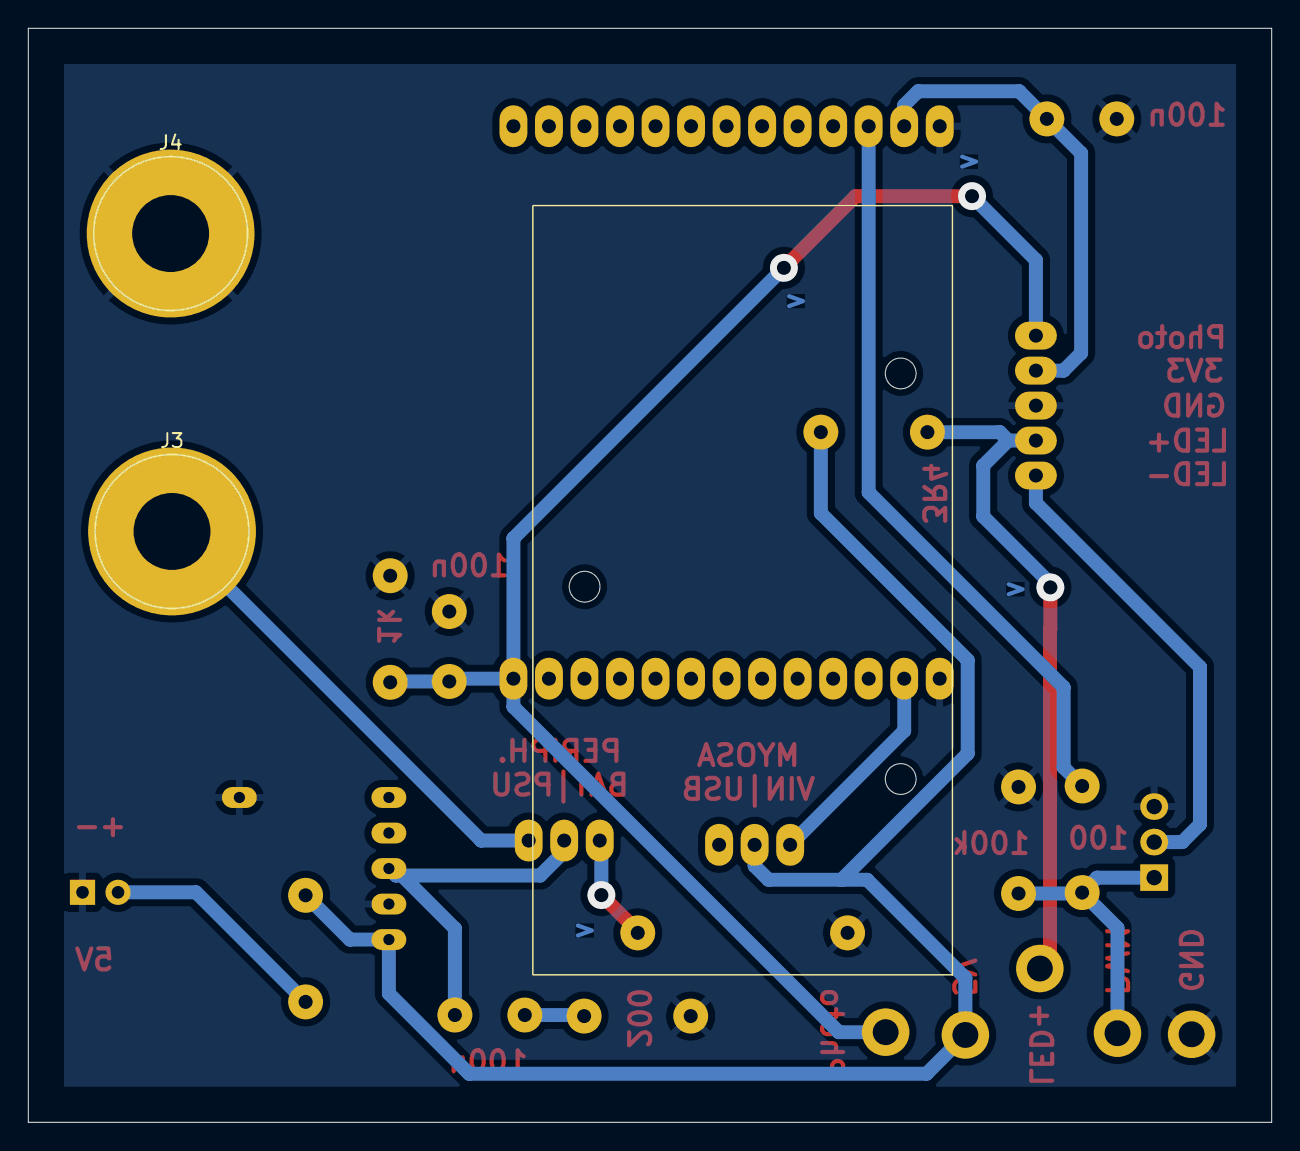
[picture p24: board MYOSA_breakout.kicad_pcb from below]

Board: 2 copper layers, 88.9 x 78.2 mm, 24 parts (3 on the bottom side), 14 nets.

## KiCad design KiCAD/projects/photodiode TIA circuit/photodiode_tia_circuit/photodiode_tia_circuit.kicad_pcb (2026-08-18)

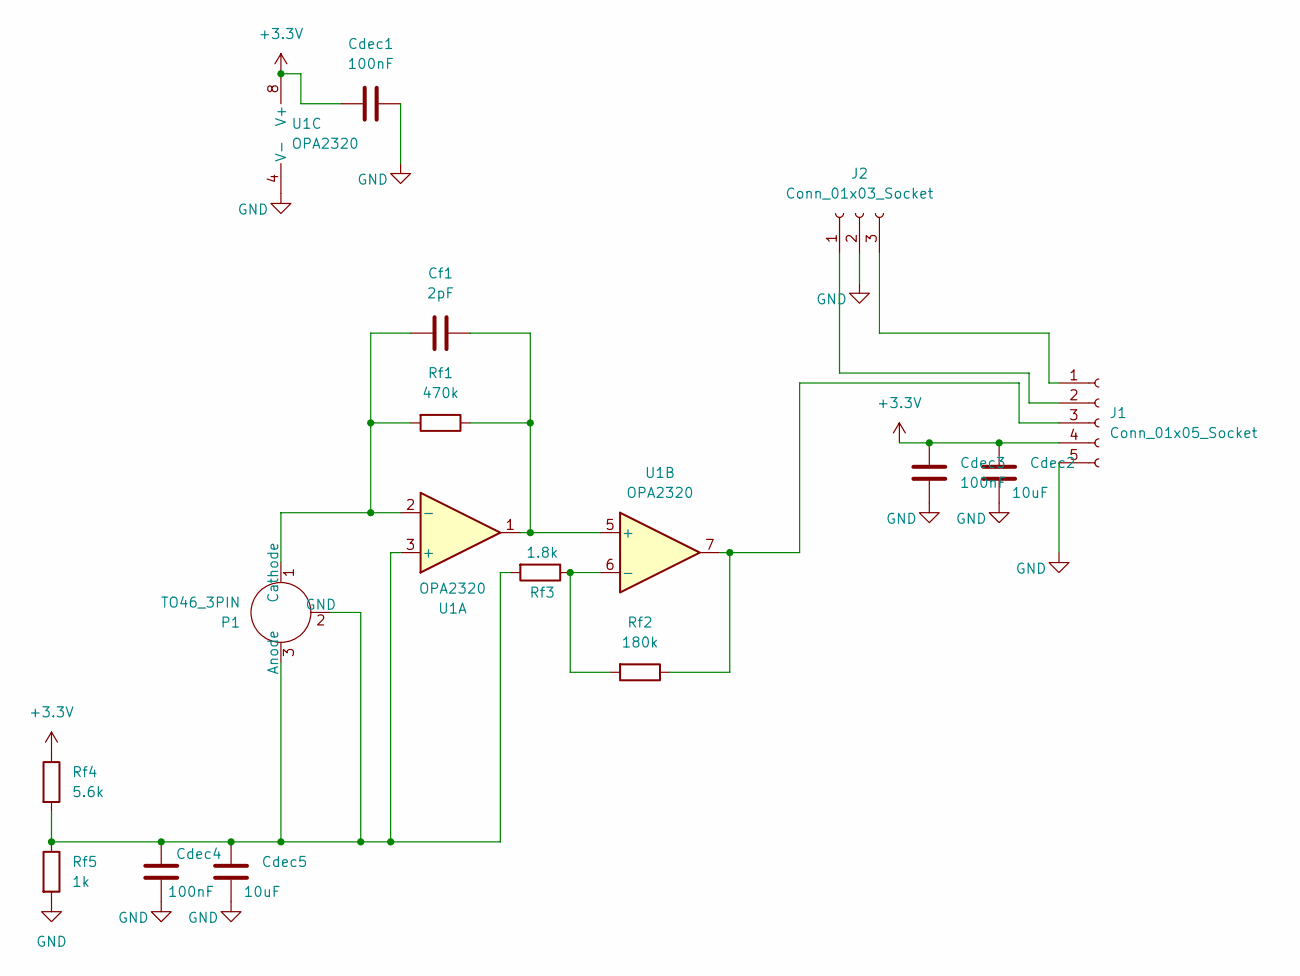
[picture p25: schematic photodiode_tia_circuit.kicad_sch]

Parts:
Cdec1, Cdec3, Cdec4: 100nF; C_Disc_D5.0mm_W2.5mm_P2.50mm
Cdec2, Cdec5: 10uF; C_Disc_D10.5mm_W5.0mm_P5.00mm
Cf1: 2pF; C_Disc_D5.0mm_W2.5mm_P2.50mm
J1: Conn_01x05_Socket; JST_EH_S5B-EH_1x05_P2.50mm_Horizontal
J2: Conn_01x03_Socket; JST_EH_S3B-EH_1x03_P2.50mm_Horizontal
P1: TO46_3PIN
Rf1: 470k; R_Axial_DIN0207_L6.3mm_D2.5mm_P10.16mm_Horizontal
Rf2: 180k; R_Axial_DIN0207_L6.3mm_D2.5mm_P10.16mm_Horizontal
Rf3: 1.8k; R_Axial_DIN0207_L6.3mm_D2.5mm_P10.16mm_Horizontal
Rf4: 5.6k; R_Axial_DIN0207_L6.3mm_D2.5mm_P10.16mm_Horizontal
Rf5: 1k; R_Axial_DIN0207_L6.3mm_D2.5mm_P10.16mm_Horizontal
U1: OPA2320; D8-M

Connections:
+3.3V: Cdec1.1, Cdec2.2, Cdec3.2, J1.4, Rf4.1, U1.8 (V+)
GND: Cdec1.2, Cdec2.1, Cdec3.1, Cdec4.1, Cdec5.1, J1.5, J2.2, Rf5.2, U1.4 (V-)
unnamed: J1.1, J2.3
unnamed: J1.2, J2.1
unnamed: J1.3, Rf2.1, U1.7
unnamed: Cdec4.2, Cdec5.2, P1.2 (GND), P1.3 (Anode), Rf3.2, Rf4.2, Rf5.1, U1.3 (+)
unnamed: Cf1.1, P1.1 (Cathode), Rf1.2, U1.2 (-)
unnamed: Cf1.2, Rf1.1, U1.1, U1.5 (+)
unnamed: Rf2.2, Rf3.1, U1.6 (-)

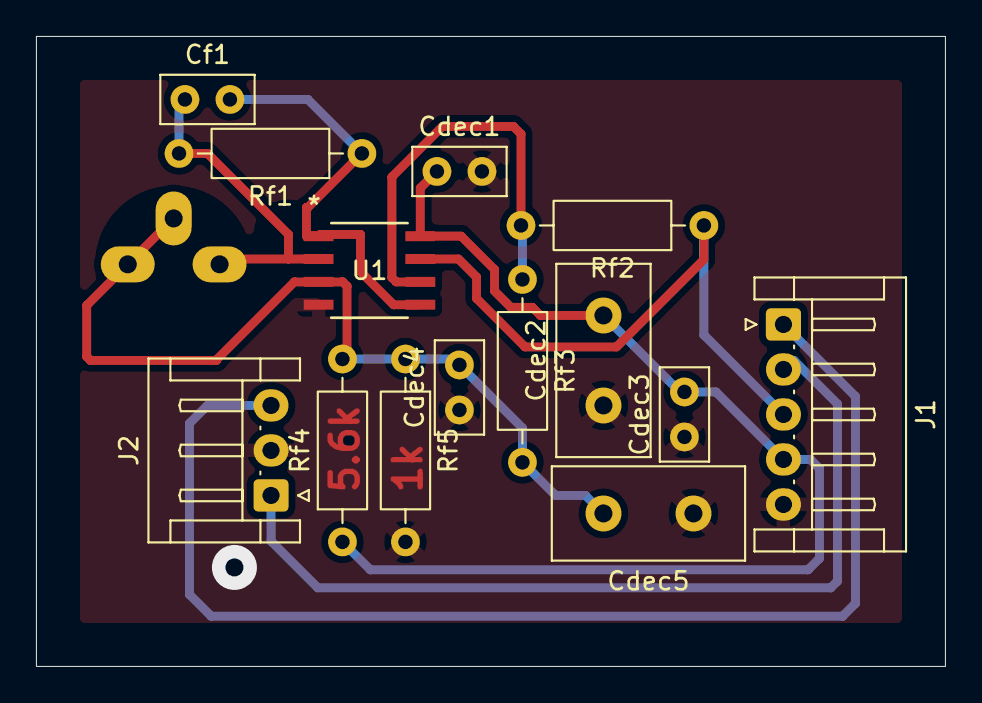
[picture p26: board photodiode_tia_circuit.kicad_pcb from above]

Board: 2 copper layers, 50.5 x 35.0 mm, 15 parts (1 on the bottom side), 9 nets.

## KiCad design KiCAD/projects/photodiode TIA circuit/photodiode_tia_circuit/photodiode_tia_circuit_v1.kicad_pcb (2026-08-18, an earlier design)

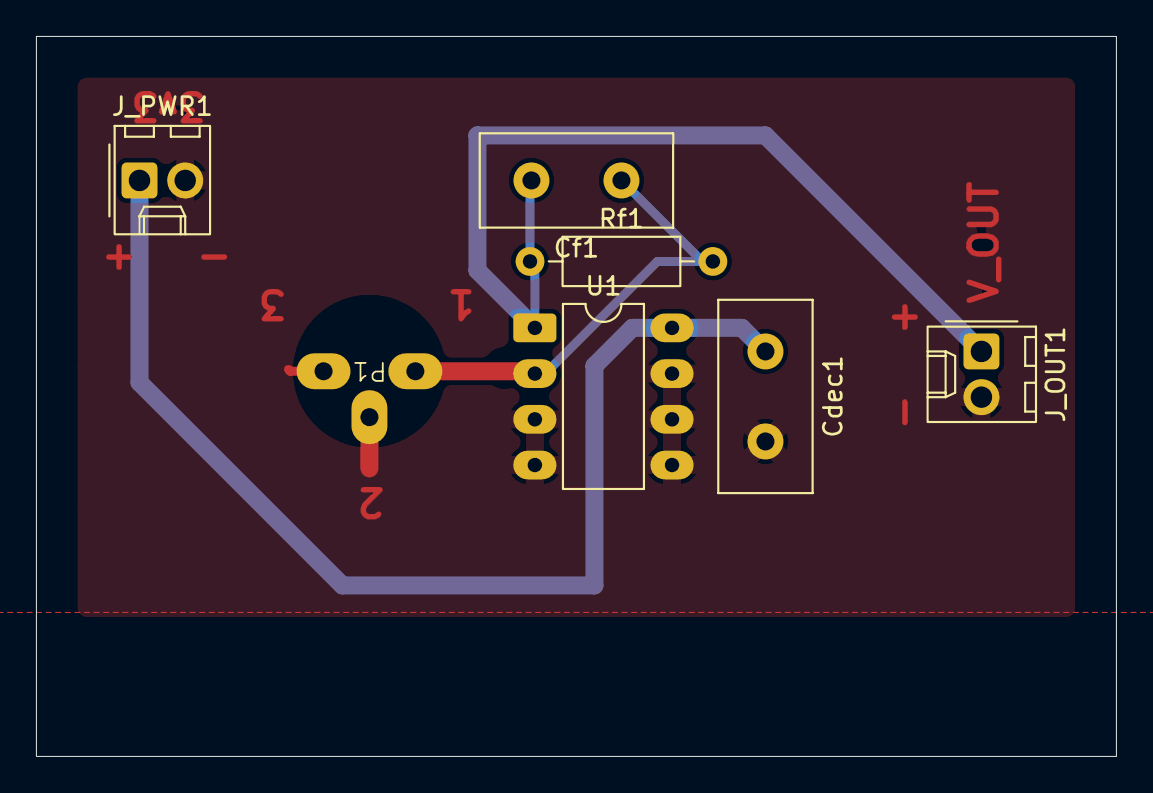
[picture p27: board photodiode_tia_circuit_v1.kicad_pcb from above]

Board: 2 copper layers, 60.0 x 40.0 mm, 7 parts (0 on the bottom side), 4 nets.

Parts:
Cdec1: 100nF; C_Disc_D10.5mm_W5.0mm_P5.00mm
Cf1: DNP; C_Disc_D10.5mm_W5.0mm_P5.00mm
J_OUT1: Conn_01x02_Socket; Molex_KK-254_AE-6410-02A_1x02_P2.54mm_Vertical
J_PWR1: Conn_01x02_Socket; Molex_KK-254_AE-6410-02A_1x02_P2.54mm_Vertical
P1: TO46_3PIN
Rf1: 10M R; R_Axial_DIN0207_L6.3mm_D2.5mm_P10.16mm_Horizontal
U1: MCP6292; DIP-8_W7.62mm_LongPads

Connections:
+3.3V: Cdec1.1, J_PWR1.1
GND: Cdec1.2, J_OUT1.2, J_PWR1.2, P1.2 (GND), P1.3 (Anode), U1.3 (+), U1.4, U1.5, U1.6, U1.7
unnamed: Cf1.2, J_OUT1.1, Rf1.1, U1.1
unnamed: Cf1.1, P1.1 (Cathode), Rf1.2, U1.2 (-)

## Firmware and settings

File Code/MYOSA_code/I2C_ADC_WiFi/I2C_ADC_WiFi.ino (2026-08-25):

// ==============================================================================
// MYOSA Sensor Firmware - ESP32
// Features: High-speed ADC sampling on Core 1, I2C (BMP180/OLED) on Core 0, 
//           and UDP transmission over a Wi-Fi SoftAP.
// ==============================================================================

// --- Bisection toggles: flip to 0 to compile that peripheral OUT entirely ---
#define ENABLE_BMP180 1
#define ENABLE_OLED   1

#include <Arduino.h>
#include <Wire.h>

#if ENABLE_BMP180
#include <BarometricPressure.h>
#endif

#if ENABLE_OLED
#include <OLED.h>            
#endif

#include "soc/gpio_reg.h"   
#include "soc/io_mux_reg.h" 
#include <WiFi.h>
#include <WiFiUdp.h>

// ==============================================================================
// HARDWARE & BUFFER CONFIGURATION
// ==============================================================================

// --- Hardware Pins ---
#define PWM_PIN 4        // Pin generating the PWM signal
#define ADC_PIN 36       // Pin reading the analog sensor data

// --- Buffer & Packet Config ---
#define BUFFER_SAMPLES 512   // Number of samples per UDP packet
#define PACKET_BUFFERS 8     // Number of packets in the ring buffer

// Magic numbers used to identify valid packets on the receiving end
#define MAGIC1 0x5049434F // "PICO" in ASCII hex
#define MAGIC2 0x41444321 // "ADC!" in ASCII hex

// --- ADC Scaling ---
#define VREF_F 3.3f           // ESP32 Reference Voltage
#define ADC_COUNTS_MAX 4095.0f // 12-bit ADC max value (2^12 - 1)

// --- Wi-Fi SoftAP & UDP Config ---
const char* ssid = "MYOSA_Sensor";
const char* password = "myosa_password"; 
const int udpPort = 12345;
WiFiUDP udp;
IPAddress broadcastIp(192, 168, 4, 255); // Broadcast address for the SoftAP subnet

// ==============================================================================
// DATA STRUCTURES
// ==============================================================================

// Packet header structure. Packed to ensure no padding bytes ruin network alignment.
typedef struct __attribute__((packed)) {
    uint32_t magic1;      // First sync word
    uint32_t magic2;      // Second sync word
    uint32_t sequence;    // Packet sequence number (for tracking ordering)
    uint32_t dropped;     // Total number of dropped buffers due to overflow
    uint16_t samples;     // Number of samples in this packet payload
    uint16_t checksum;    // Simple additive checksum of the payload
    float temperature;    // Last read temperature from BMP180
    float pressure;       // Last read pressure from BMP180
} packet_header_t;

// Complete packet structure holding both header and ADC payload
typedef struct {
    packet_header_t header;
    uint16_t samples[BUFFER_SAMPLES]; // Payload: MSB holds PWM state, 15 LSBs hold ADC
    volatile bool ready;              // Flag indicating buffer is full and ready to send
} packet_t;

// ==============================================================================
// GLOBAL VARIABLES
// ==============================================================================

// Ring buffer for packets
static packet_t packets[PACKET_BUFFERS];

// State tracking variables
static volatile uint32_t sequence_number = 0;
static volatile uint32_t dropped_buffers = 0;
static volatile uint8_t write_index = 0;   // Where Core 1 is currently writing data
static volatile uint8_t read_index = 0;    // Where Core 0 is currently reading data to send
static volatile uint16_t sample_index = 0; // Current sample within the active buffer

// Sensor objects and states
BarometricPressure Pr(ULTRA_LOW_POWER);
static float current_temp = 0.0f;
static float current_pressure = 0.0f;

oLed display(128, 64);
bool display_active = false;
bool bmp_active = false;

// Variables for calculating average voltage based on PWM state
static volatile uint32_t sum_on = 0;
static volatile uint32_t sum_off = 0;
static volatile uint16_t count_on = 0;
static volatile uint16_t count_off = 0;
static volatile float led_on_avg_v = 0.0f;
static volatile float led_off_avg_v = 0.0f;

// Baseline calibration variables for breath/blow detection
#define BASELINE_CAPTURE_PACKETS 50
static volatile bool baseline_captured = false;
static volatile float baseline_delta_v = 0.0f;
static volatile uint16_t baseline_packet_count = 0;
#define BLOW_THRESHOLD_V 0.02f // Minimum voltage delta to trigger a "blow" event

// RTOS Mutex to prevent Core 0 and Core 1 from corrupting ring buffer states
portMUX_TYPE bufferMux = portMUX_INITIALIZER_UNLOCKED;

// ==============================================================================
// HELPER FUNCTIONS
// ==============================================================================

// Calculates a simple 16-bit additive checksum for data verification
static uint16_t checksum_u16(const uint16_t *data, uint16_t n) {
    uint32_t sum = 0;
    for (uint16_t i = 0; i < n; i++) {
        sum += data[i];
    }
    return (uint16_t)(sum & 0xFFFF);
}

// ==============================================================================
// RTOS TASKS
// ==============================================================================

// --- Core 1 Task: High-Speed ADC Polling ---
// Continuously polls the ADC and PWM pins as fast as possible, packages the data,
// and hands it off to the UDP transmission loop.
void adcTaskFunc(void * pvParameters) {
    for(;;) {
        packet_t *packet = &packets[write_index];

        // If the current buffer hasn't been sent yet, we are dropping data
        if (packet->ready) {
            dropped_buffers++;
            vTaskDelay(1); // Yield briefly to let the UDP task catch up
            continue;
        }

        // Fast hardware read: ADC value and raw GPIO state of the PWM pin
        uint16_t adc_val = analogRead(ADC_PIN);
        uint16_t pwm_state = (REG_READ(GPIO_IN_REG) >> PWM_PIN) & 0x1;
        
        // Pack PWM state into the 16th bit (MSB) of the ADC value
        packet->samples[sample_index] = adc_val | (pwm_state << 15);
        sample_index++;

        // Accumulate data to calculate average voltages later
        if (pwm_state) {
            sum_on += adc_val;
            count_on++;
        } else {
            sum_off += adc_val;
            count_off++;
        }

        // When the buffer fills up, seal the packet and advance the write index
        if (sample_index >= BUFFER_SAMPLES) {
            // Populate packet header
            packet->header.magic1 = MAGIC1;
            packet->header.magic2 = MAGIC2;
            packet->header.sequence = sequence_number++;
            packet->header.dropped = dropped_buffers;
            packet->header.samples = BUFFER_SAMPLES;
            packet->header.checksum = checksum_u16(packet->samples, BUFFER_SAMPLES);
            
            // CRITICAL SECTION: Update ring buffer index safely
            portENTER_CRITICAL(&bufferMux);
            packet->ready = true;
            write_index++;
            if (write_index >= PACKET_BUFFERS) write_index = 0;
            portEXIT_CRITICAL(&bufferMux);
            
            sample_index = 0; // Reset for next packet

            // Calculate averages and handle baseline calibration
            if (count_on > 0 && count_off > 0) {
                led_on_avg_v = ((float)sum_on / (float)count_on) * (VREF_F / ADC_COUNTS_MAX);
                led_off_avg_v = ((float)sum_off / (float)count_off) * (VREF_F / ADC_COUNTS_MAX);

                // Initial baseline capture routine
                if (!baseline_captured) {
                    baseline_delta_v += (led_on_avg_v - led_off_avg_v);
                    baseline_packet_count++;
                    
                    if (baseline_packet_count >= BASELINE_CAPTURE_PACKETS) {
                        baseline_delta_v /= (float)baseline_packet_count; // Average the baseline
                        baseline_captured = true;
                    }
                }
            }
            
            // Reset accumulators for the next buffer
            sum_on = 0; sum_off = 0; count_on = 0; count_off = 0;
            
            // Feed the RTOS Watchdog Timer so the ESP doesn't reboot
            yield(); 
        }
    }
}

// --- Core 0 Task: Slow I2C Operations ---
// Handles the BMP180 sensor and OLED display. Pinned to Core 0 so blocking 
// I2C calls do not interrupt the high-speed ADC polling on Core 1.
void baroTaskFunc(void * pvParameters) {
    Wire.begin();
    Wire.setClock(100000); // Standard I2C speed (100kHz)
    
    // Give the I2C bus a moment to stabilize
    vTaskDelay(100 / portTICK_PERIOD_MS);

    // Retry loop for BMP180 initialization (matches MYOSA demo script logic)
    for (int i = 0; i < 5; i++) {
        bmp_active = Pr.begin();
        if (bmp_active) {
            Serial.println("BMP180 begin() OK");
            break;
        }
        Serial.println("BMP180 begin() failed. Retrying...");
        vTaskDelay(500 / portTICK_PERIOD_MS);
    }
    
    if (!bmp_active) Serial.println("BMP180 permanently bypassed.");
    
    // Initialize OLED Display
    display_active = display.begin();
    if (!display_active) Serial.println("OLED begin() failed. Bypassing.");

    // Endless task loop updating at 1Hz
    for(;;) {
        // Read barometric data if sensor is connected
        if(bmp_active && Pr.ping()) {
            current_temp = Pr.getTempC();
            current_pressure = Pr.getPressurePascal();
        }

        // Update OLED UI if display is connected
        if (display_active) {
            float delta_v = led_on_avg_v - led_off_avg_v;
            bool blowing = baseline_captured && ((delta_v - baseline_delta_v) > BLOW_THRESHOLD_V);

            display.clearDisplay();
            
            // --- Row 1: Barometer Status & Temperature ---
            display.setTextSize(1);
            display.setCursor(0, 0);
            if (bmp_active) {
                display.print("Baro: OK  T: "); 
                display.print(current_temp, 1); 
                display.print("C");
            } else {
                display.print("Baro: DISCONNECTED");
            }

            // --- Row 2: Photodiode Status (> 0.2V Check) ---
            display.setCursor(0, 16);
            if (led_on_avg_v > 0.2f) {
                display.print("PD: CONN ("); 
                display.print(led_on_avg_v, 2); 
                display.print("V)");
            } else {
                display.print("PD: MISSING (<0.2V)");
            }

            // --- Row 3: Pressure / UDP Health ---
            display.setCursor(0, 32);
            if (bmp_active) {
                display.print("P: "); 
                display.print(current_pressure, 0); 
                display.print(" Pa");
            } else {
                // If baro is unplugged, show UDP buffer drop stats instead
                display.print("Drops: "); 
                display.print(dropped_buffers);
            }

            // --- Row 4: Breath Status (Large Text) ---
            display.setCursor(0, 48);
            display.setTextSize(2);
            if (!baseline_captured) display.print("CALIB...");
            else if (blowing) display.print("BLOWING");
            else display.print("IDLE");

            display.display();
        }
        
        // Delay 1 second (1Hz refresh rate)
        vTaskDelay(1000 / portTICK_PERIOD_MS); 
    }
}

// ==============================================================================
// MAIN SETUP & LOOP
// ==============================================================================

void setup() {
    Serial.begin(115200); 

    // Setup Wi-Fi Access Point
    WiFi.mode(WIFI_AP);
    WiFi.softAP(ssid, password);
    udp.begin(udpPort);
    Serial.print("AP IP address: ");
    Serial.println(WiFi.softAPIP());

    // Initialize packet ring buffer ready states
    for (uint8_t i = 0; i < PACKET_BUFFERS; i++) packets[i].ready = false;

    // Configure PWM output and ADC resolution
    ledcAttach(PWM_PIN, 100, 12); // PWM on Pin 4, 100Hz, 12-bit resolution
    ledcWrite(PWM_PIN, 82);       // Duty cycle
    REG_SET_BIT(IO_MUX_GPIO4_REG, FUN_IE); // Ensure GPIO4 input is enabled so we can read its state
    analogReadResolution(12);     // 12-bit ADC (0-4095)

    // Launch FreeRTOS Tasks on specific cores
    // Core 0 handles slow I2C (OLED/BMP180)
    xTaskCreatePinnedToCore(baroTaskFunc, "BaroTask", 10240, NULL, 1, NULL, 0);

    // Core 1 handles fast ADC polling (replaces standard timer interrupts)
    xTaskCreatePinnedToCore(adcTaskFunc, "AdcTask", 8192, NULL, 2, NULL, 1);
}

void loop() {
    packet_t *packet = &packets[read_index];

    // If Core 1 has marked the current buffer as ready, send it over UDP
    if (packet->ready) {
        // Tag packet with the latest slow sensor readings before sending
        packet->header.temperature = current_temp;
        packet->header.pressure = current_pressure;

        // Transmit UDP Broadcast
        udp.beginPacket(broadcastIp, udpPort);
        udp.write((uint8_t*)&packet->header, sizeof(packet_header_t));
        udp.write((uint8_t*)packet->samples, BUFFER_SAMPLES * sizeof(uint16_t));
        udp.endPacket();

        // CRITICAL SECTION: Free the buffer back to Core 1 and advance index
        portENTER_CRITICAL(&bufferMux);
        packet->ready = false;
        read_index++;
        if (read_index >= PACKET_BUFFERS) read_index = 0;
        portEXIT_CRITICAL(&bufferMux);
    }
    
    // Yield to let background network processes run
    yield(); 
}

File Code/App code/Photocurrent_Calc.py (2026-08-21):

import csv
import socket
import struct
import sys
import threading
import time
from collections import deque

import numpy as np
import pyqtgraph as pg
from PyQt6 import QtCore, QtWidgets

# --- UDP Configuration ---
UDP_IP = "0.0.0.0"  # Listen on all network adapters
UDP_PORT = 12345

# --- Packet configuration ---
EXPECTED_SAMPLES = 512
MAGIC_BYTES = b"OCIP!CDA"
# sequence, dropped, samples, checksum, temperature, pressure
HEADER_REST_FMT = "<I I H H f f"
HEADER_REST_SIZE = struct.calcsize(HEADER_REST_FMT)

# --- ADC scaling ---
VREF = 3.3
ADC_MAX = 4095.0
ADC_SAMPLE_RATE_HZ = 200000

# --- Rolling buffer sizes ---
ROLLING_ADC_SAMPLES = 8192
ROLLING_BARO_POINTS = 600  # ~10 min at 1 reading/sec
ROLLING_LED_POINTS = 600   # ~10 min of LED on/off + photocurrent history

# --- 10 ms historical averaging window ---
LED_AVG_WINDOW_S = 0.010
LED_AVG_WINDOW_SAMPLES = int(LED_AVG_WINDOW_S * ADC_SAMPLE_RATE_HZ)  # 2000 samples

# --- TIA / analogue front-end model (see Figure 5.2 schematic) ---
TIA_RF_OHMS = 120e3          # Rf1, transimpedance feedback resistor
STAGE2_GAIN = 1 + (240e3 / 1e3)  # Av = 1 + Rf2/Rf3 = 241
TOTAL_TRANSIMPEDANCE = TIA_RF_OHMS * STAGE2_GAIN  # V per A, overall gain

# Photosensitivity temperature coefficient of the InAsSb detector
# (~ -0.1 %/degC around the 4.3 um band, back-illuminated type, per datasheet)
ALPHA_PD_PER_DEGC = -0.001
T0_REF_DEGC = 25.0

# --- Shared state (guarded by `lock`) ---
lock = threading.Lock()
running = True

rolling_volts = np.array([], dtype=np.float32)
rolling_pwm = np.array([], dtype=np.uint8)
latest_status = "Waiting..."

baro_t = deque(maxlen=ROLLING_BARO_POINTS)      # wall-clock seconds
baro_temp = deque(maxlen=ROLLING_BARO_POINTS)   # deg C
baro_pressure = deque(maxlen=ROLLING_BARO_POINTS)  # Pa
baro_start_time = None
latest_temp = None
latest_pressure = None


def checksum_u16(adc_u16):
    return int(np.sum(adc_u16, dtype=np.uint32) & 0xFFFF)


def udp_thread():
    global rolling_volts, rolling_pwm, latest_status
    global baro_start_time, latest_temp, latest_pressure

    # Initialize a UDP socket
    sock = socket.socket(socket.AF_INET, socket.SOCK_DGRAM)
    sock.bind((UDP_IP, UDP_PORT))
    sock.settimeout(0.1)

    expected_size = len(MAGIC_BYTES) + HEADER_REST_SIZE + (EXPECTED_SAMPLES * 2)

    try:
        while running:
            try:
                # UDP guarantees we get exactly the message sent by endPacket()
                data, addr = sock.recvfrom(2048)
            except socket.timeout:
                continue
            except OSError:
                break

            # Ignore malformed or fragmented packets
            if len(data) != expected_size:
                continue

            # Verify Magic Bytes
            if data[:len(MAGIC_BYTES)] != MAGIC_BYTES:
                continue

            packet_start = len(MAGIC_BYTES)
            rest = data[packet_start : packet_start + HEADER_REST_SIZE]
            raw = data[packet_start + HEADER_REST_SIZE :]

            (_sequence, _dropped, samples, checksum,
             temperature, pressure) = struct.unpack(HEADER_REST_FMT, rest)

            if samples != EXPECTED_SAMPLES:
                continue

            adc_u16 = np.frombuffer(raw, dtype="<u2").copy()
            if checksum_u16(adc_u16) != checksum:
                continue

            pwm_state = ((adc_u16 >> 15) & 0x1).astype(np.uint8)
            adc_u16 = adc_u16 & 0x0FFF
            volts = adc_u16.astype(np.float32) * (VREF / ADC_MAX)

            status = f"min={volts.min():.3f} V | max={volts.max():.3f} V | Dropped={_dropped}"
            now = time.time()

            with lock:
                rolling_volts = np.concatenate((rolling_volts, volts))
                rolling_pwm = np.concatenate((rolling_pwm, pwm_state))
                if len(rolling_volts) > ROLLING_ADC_SAMPLES:
                    rolling_volts = rolling_volts[-ROLLING_ADC_SAMPLES:]
                    rolling_pwm = rolling_pwm[-ROLLING_ADC_SAMPLES:]

                latest_status = status

                if baro_start_time is None:
                    baro_start_time = now

                baro_t.append(now - baro_start_time)
                baro_temp.append(float(temperature))
                baro_pressure.append(float(pressure))
                latest_temp = temperature
                latest_pressure = pressure

    finally:
        sock.close()


def find_trigger_window(signal, trace_length, level, edge, pretrigger_frac=0.25):
    """
    Scan `signal` for the most recent level-crossing that still leaves a full
    `trace_length` window available (with `pretrigger_frac` of it before the
    trigger point), mimicking a real oscilloscope's trigger + pre-trigger view.

    Returns (start, end, trigger_index) or None if no valid crossing is found.
    """
    n = len(signal)
    if n < 2 or trace_length < 2:
        return None

    pretrigger = int(trace_length * pretrigger_frac)

    if edge == "Rising":
        idxs = np.where((signal[:-1] < level) & (signal[1:] >= level))[0] + 1
    else:  # "Falling"
        idxs = np.where((signal[:-1] >= level) & (signal[1:] < level))[0] + 1

    # Walk backwards from the most recent crossing until one fits in the buffer
    for idx in idxs[::-1]:
        start = idx - pretrigger
        end = start + trace_length
        if start >= 0 and end <= n:
            return start, end, idx

    return None
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

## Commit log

2026-08-19 New Code for sensors + WiFi
2026-08-21 Code updates
    [capture_adc.csv, capture_baro.csv]
2026-08-24 Code and App updates
    [capture_adc.csv, capture_baro.csv]
2026-08-25 Stop tracking old_ver folders
    [capture_adc.csv, capture_baro.csv]
2026-08-25 Added Mechanical CAD to repo
    [12C_Mouthpiece.stl, Adapter.SLDPRT, Adapter.STL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]
